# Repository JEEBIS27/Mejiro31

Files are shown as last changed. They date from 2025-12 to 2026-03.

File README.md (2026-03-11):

# Mejiro31

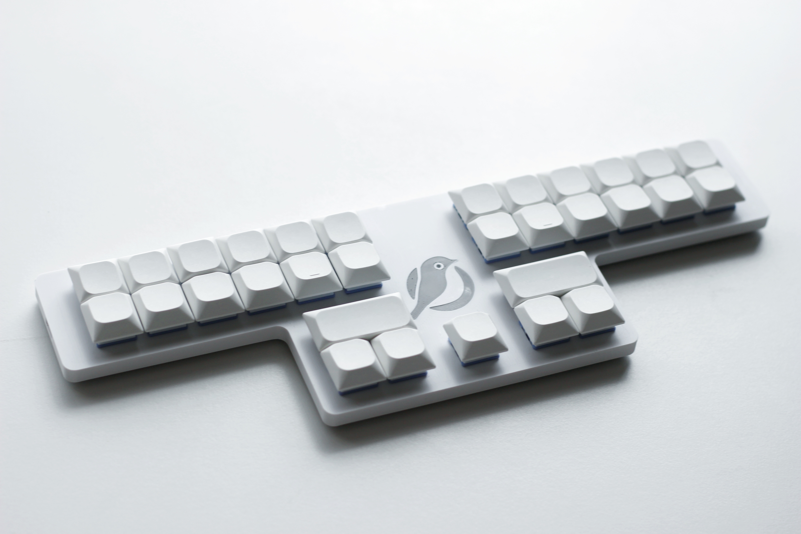
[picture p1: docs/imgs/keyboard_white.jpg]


## 組み立て方 / How to Build
- [Mejiro31 の組み立て方](/docs/BUILD.md)
- [How to Build Mejiro31](/docs/BUILD_EN.md)

## 使い方 / How to Use
- [Mejiro31 の使い方](/docs/USAGE.md)
- [How to Use Mejiro31](/docs/USAGE_EN.md)

## ファームウェア一覧 / Firmware List

### 日本語配列用 / Firmware for Japanese Layout
- [QWERTY 配列](https://github.com/JEEBIS27/Mejiro31/releases/download/v0.3.6/mejiro31_jp_qwerty.uf2)
- [Dvorak 配列](https://github.com/JEEBIS27/Mejiro31/releases/download/v0.3.6/mejiro31_jp_dvorak.uf2)
- [Boo 配列](https://github.com/JEEBIS27/Mejiro31/releases/download/v0.3.6/mejiro31_jp_boo.uf2)
- [Colemak 配列](https://github.com/JEEBIS27/Mejiro31/releases/download/v0.3.6/mejiro31_jp_colemak.uf2)
- [Colemak-DH 配列](https://github.com/JEEBIS27/Mejiro31/releases/download/v0.3.6/mejiro31_jp_colemak-dh.uf2)
- [Workman 配列](https://github.com/JEEBIS27/Mejiro31/releases/download/v0.3.6/mejiro31_jp_workman.uf2)
- [Graphite 配列](https://github.com/JEEBIS27/Mejiro31/releases/download/v0.3.6/mejiro31_jp_graphite.uf2)
- [Astarte 配列](https://github.com/JEEBIS27/Mejiro31/releases/download/v0.3.6/mejiro31_jp_astarte.uf2)
- [Eucalyn 配列](https://github.com/JEEBIS27/Mejiro31/releases/download/v0.3.6/mejiro31_jp_eucalyn.uf2)
- [Eucalyn 改](https://github.com/JEEBIS27/Mejiro31/releases/download/v0.3.6/mejiro31_jp_eucalyn-biacco.uf2)
- [Tomisuke 配列](https://github.com/JEEBIS27/Mejiro31/releases/download/v0.3.6/mejiro31_jp_tomisuke.uf2)
- [大西配列](https://github.com/JEEBIS27/Mejiro31/releases/download/v0.3.6/mejiro31_jp_o24.uf2)
- [Merlin 配列](https://github.com/JEEBIS27/Mejiro31/releases/download/v0.3.6/mejiro31_jp_merlin.uf2)
### 英語配列用 / Firmware for English Layout
- [QWERTY Layout](https://github.com/JEEBIS27/Mejiro31/releases/download/v0.3.6/jeeb1s_mejiro31_en_qwerty.uf2)
- [Dvorak Layout](https://github.com/JEEBIS27/Mejiro31/releases/download/v0.3.6/mejiro31_en_dvorak.uf2)
- [Boo Layout](https://github.com/JEEBIS27/Mejiro31/releases/download/v0.3.6/mejiro31_en_boo.uf2)
- [Colemak Layout](https://github.com/JEEBIS27/Mejiro31/releases/download/v0.3.6/mejiro31_en_colemak.uf2)
- [Colemak-DH Layout](https://github.com/JEEBIS27/Mejiro31/releases/download/v0.3.6/mejiro31_en_colemak-dh.uf2)
- [Workman Layout](https://github.com/JEEBIS27/Mejiro31/releases/download/v0.3.6/mejiro31_en_workman.uf2)
- [Graphite Layout](https://github.com/JEEBIS27/Mejiro31/releases/download/v0.3.6/mejiro31_en_graphite.uf2)
- [Gallium Layout](https://github.com/JEEBIS27/Mejiro31/releases/download/v0.3.6/mejiro31_en_gallium.uf2)
- [Handsdown-neu Layout](https://github.com/JEEBIS27/Mejiro31/releases/download/v0.3.6/mejiro31_en_handsdown-neu.uf2)
- [Sturdy Layout](https://github.com/JEEBIS27/Mejiro31/releases/download/v0.3.6/mejiro31_en_sturdy.uf2)
- [Canary Layout](https://github.com/JEEBIS27/Mejiro31/releases/download/v0.3.6/mejiro31_en_canary.uf2)
- [Engram Layout](https://github.com/JEEBIS27/Mejiro31/releases/download/v0.3.6/mejiro31_en_engram.uf2)

## ビルド環境の構築 / How to Build Firmware

ファームウェアのソースコード / Firmware Source Code
- https://github.com/JEEBIS27/qmk_firmware/tree/master/keyboards/jeebis/mejiro31

ファームウェアをクローンする / Cloning the Repo for Firmware Build
```
git clone https://github.com/JEEBIS27/qmk_firmware.git
```

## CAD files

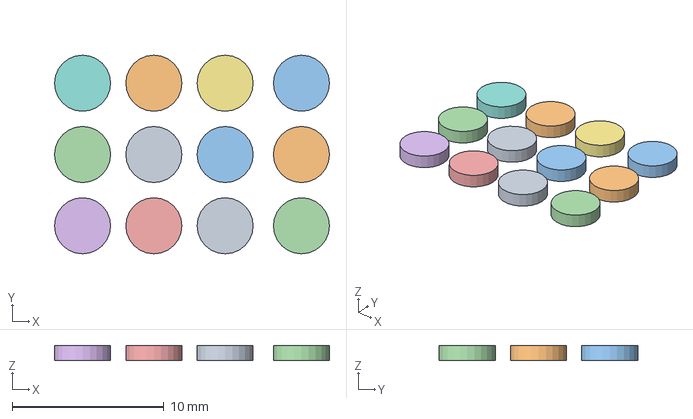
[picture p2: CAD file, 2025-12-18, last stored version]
3D/Mejiro31-PCBA_eye.3mf
18.1 x 13.1 x 1.00 mm
Mejiro31-PCBA_eye x 12

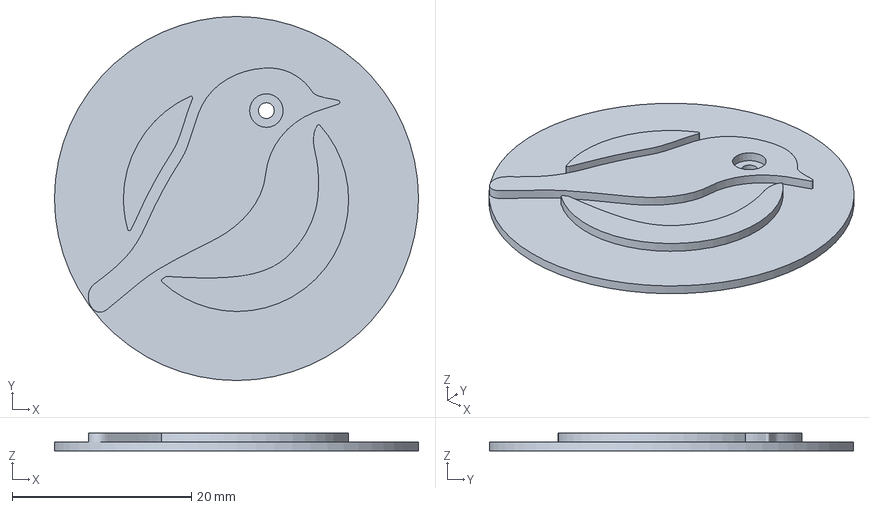
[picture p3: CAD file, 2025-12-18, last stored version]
3D/Mejiro31-PCBA_icon.3mf
40.6 x 40.6 x 2.00 mm

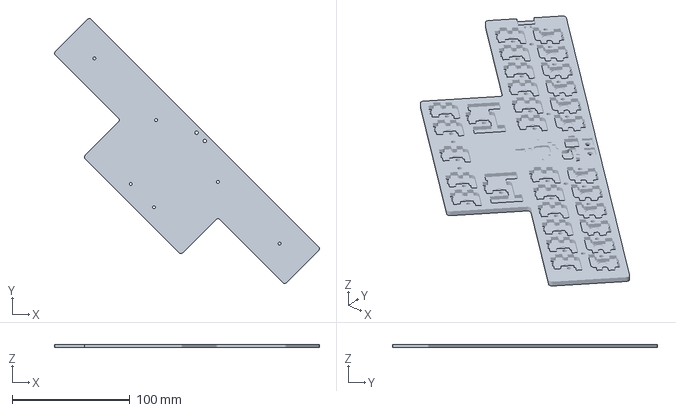
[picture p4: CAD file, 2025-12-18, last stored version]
3D/Mejiro31-PCBA_foam.3mf
224.7 x 224.7 x 2.60 mm

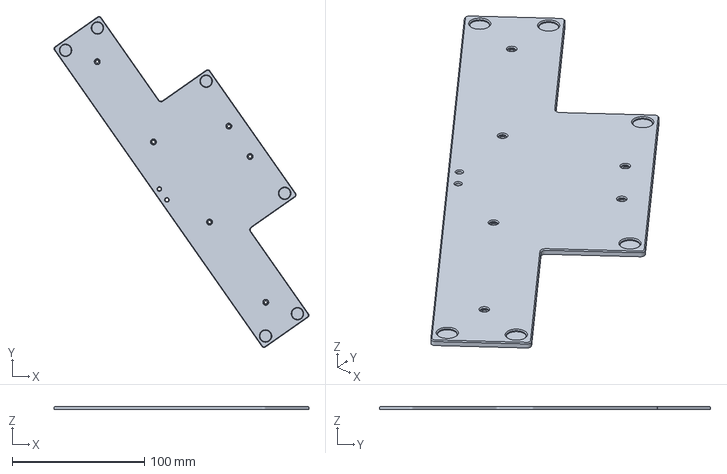
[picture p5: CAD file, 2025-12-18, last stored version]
3D/Mejiro31-PCBA_bottom.3mf
192.6 x 250.1 x 2.50 mm

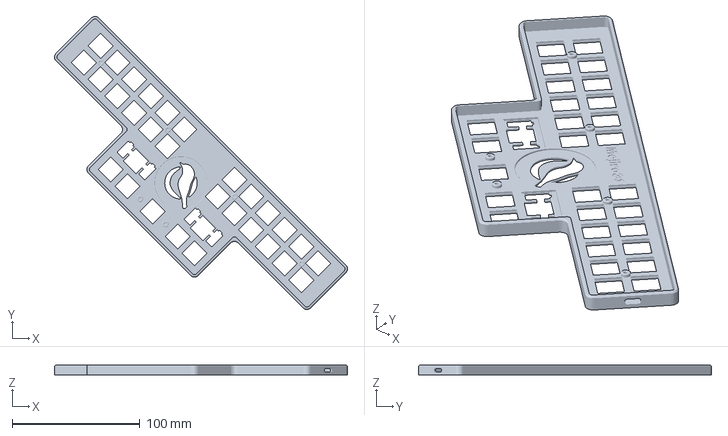
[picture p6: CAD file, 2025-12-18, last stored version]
3D/Mejiro31-PCBA_top.3mf
229.0 x 229.0 x 7.60 mm

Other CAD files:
3D/Mejiro31-PCBA_bottom.stl
3D/Mejiro31-PCBA_foam.stl
3D/Mejiro31-PCBA_icon.stl
3D/Mejiro31-PCBA_top.stl

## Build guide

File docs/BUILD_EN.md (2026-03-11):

# How to Build Mejiro31 ([Back to Start Page](../README.md))

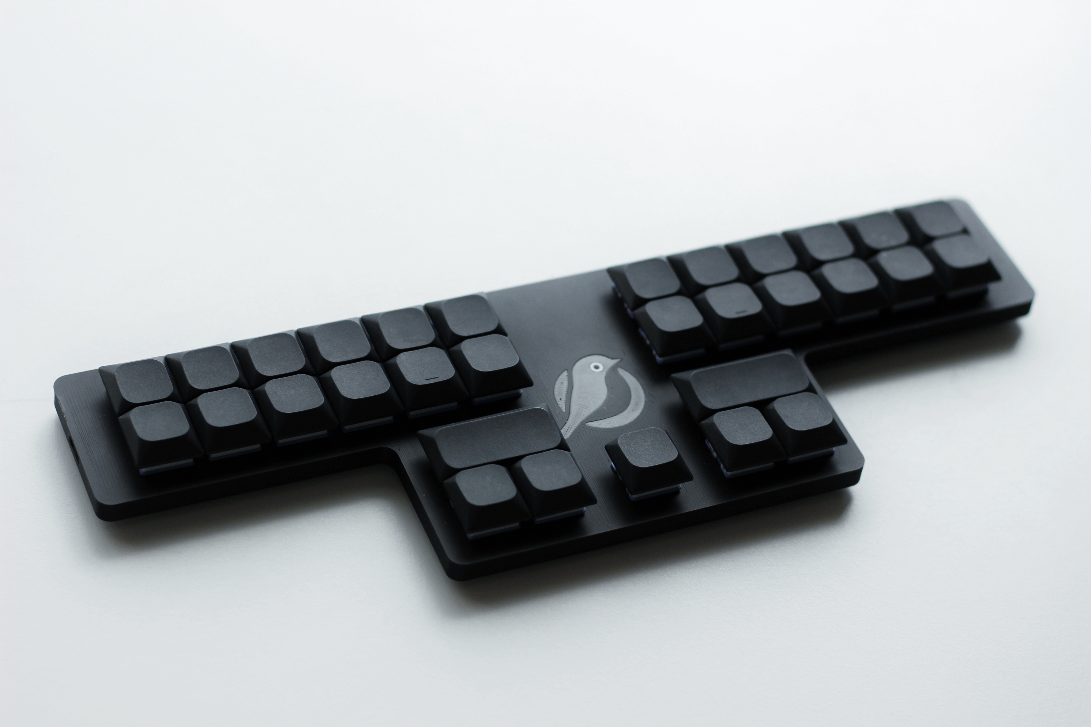
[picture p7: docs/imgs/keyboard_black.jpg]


## Table of Contents
  1. [What You Need Besides the Kit](#1-what-you-need-besides-the-kit)
  2. [Check the Contents](#2-check-the-contents)
  3. [Assembly](#3-assembly)
  4. [Troubleshooting](#4-troubleshooting)
  5. [Contact Us](#5-contact-us)

## 1. What You Need Besides the Kit

| Item | Quantity |
| ---- | --- |
| Keycaps | 31 |
| Key switches | 31 |
| USB-C cable | 1 |
| Precision screwdriver | 1 |
| Pliers | 1 |

### Key Switch Compatibility

Mejiro31 only supports low-profile key switches.

By default, only Cherry MX-compatible [Gateron low-profile 3.0](https://www.amazon.co.jp/dp/B0FJXBL4BF) switches work without soldering.

If you want to use the Kailh Choc V2 series, you need to solder [sockets for Kailh Choc](https://shop.yushakobo.jp/products/a01ps?variant=37665172553889).

### Recommended Key Switches

Here are some recommended switches for your reference.

| Switch | Feature | Actuation | Soldering |
| --- | --- | --- | --- |
| [Gateron low-profile 3.0](https://www.amazon.co.jp/dp/B0FJXBL4BF) | Standard feel | 50~43g | Not required |
| [Nuphy Gateron low-profile 3.0](https://sanyollc.com/products/nuphy-gateron-low-profile-3-0-switches) | POM material | 45~37g | Not required |
| [Lofree Hades POM](https://lofree.co.jp/products/hades-low-profile-pom-switches) | Silent | 40g | Required |
| [Kailh Saker mini](https://shop.talpkeyboard.com/products/kailh-saker-chocv2-linear) | Short travel | 37g | Required |
| [Kailh Choc v2 Panda V1](https://ja.aliexpress.com/item/1005008329710988.html) | Lightweight | 30g | Required |
| [Kailh Choc V1 Pink](https://shop.yushakobo.jp/products/pg1350?variant=44079245754599) | Lightest | 20g | Required |

## 2. Check the Contents

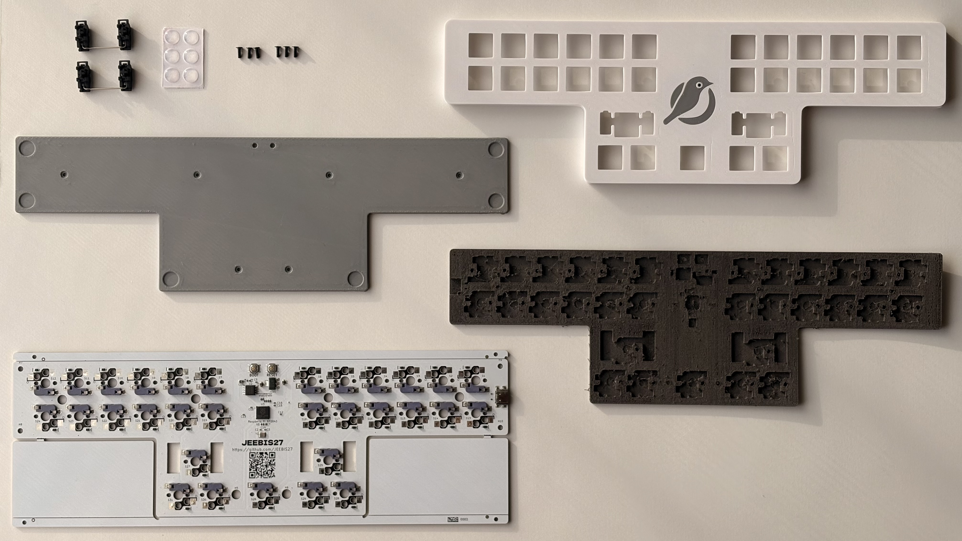
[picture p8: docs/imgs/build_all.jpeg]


| Included | Quantity |
| --- | --- |
| PCB | 1 |
| Top plate | 1 |
| Bottom plate | 1 |
| Foam plate | 1 |
| Stabilizers | 2 |
| Screws | 6 |
| Rubber feet | 6 |

## 3. Assembly

Download the firmware file first.

If you want to use a standard QWERTY layout, download [this file](https://github.com/JEEBIS27/Mejiro31/releases/download/v0.3.6/mejiro31_en_qwerty.uf2).

For other layouts, download from the links below:
- [QWERTY Layout](https://github.com/JEEBIS27/Mejiro31/releases/download/v0.3.6/mejiro31_en_qwerty.uf2)
- [Dvorak Layout](https://github.com/JEEBIS27/Mejiro31/releases/download/v0.3.6/mejiro31_en_dvorak.uf2)
- [Boo Layout](https://github.com/JEEBIS27/Mejiro31/releases/download/v0.3.6/mejiro31_en_boo.uf2)
- [Colemak Layout](https://github.com/JEEBIS27/Mejiro31/releases/download/v0.3.6/mejiro31_en_colemak.uf2)
- [Colemak-DH Layout](https://github.com/JEEBIS27/Mejiro31/releases/download/v0.3.6/mejiro31_en_colemak-dh.uf2)
- [Workman Layout](https://github.com/JEEBIS27/Mejiro31/releases/download/v0.3.6/mejiro31_en_workman.uf2)
- [Graphite Layout](https://github.com/JEEBIS27/Mejiro31/releases/download/v0.3.6/mejiro31_en_graphite.uf2)
- [Astarte Layout](https://github.com/JEEBIS27/Mejiro31/releases/download/v0.3.6/mejiro31_en_astarte.uf2)
- [Eucalyn Layout](https://github.com/JEEBIS27/Mejiro31/releases/download/v0.3.6/mejiro31_en_eucalyn.uf2)
- [Eucalyn Modified](https://github.com/JEEBIS27/Mejiro31/releases/download/v0.3.6/mejiro31_en_eucalyn.uf2)
- [Tomisuke Layout](https://github.com/JEEBIS27/Mejiro31/releases/download/v0.3.6/mejiro31_en_tomisuke.uf2)
- [Onishi Layout](https://github.com/JEEBIS27/Mejiro31/releases/download/v0.3.6/mejiro31_en_o24.uf2)
- [Merlin Layout](https://github.com/JEEBIS27/Mejiro31/releases/download/v0.3.6/mejiro31_en_merlin.uf2)
- [Gallium Layout](https://github.com/JEEBIS27/Mejiro31/releases/download/v0.3.6/mejiro31_en_gallium.uf2)
- [Handsdown-neu Layout](https://github.com/JEEBIS27/Mejiro31/releases/download/v0.3.6/mejiro31_en_handsdown-neu.uf2)
- [Sturdy Layout](https://github.com/JEEBIS27/Mejiro31/releases/download/v0.3.6/mejiro31_en_sturdy.uf2)
- [Canary Layout](https://github.com/JEEBIS27/Mejiro31/releases/download/v0.3.6/mejiro31_en_canary.uf2)
- [Engram Layout](https://github.com/JEEBIS27/Mejiro31/releases/download/v0.3.6/mejiro31_en_engram.uf2)

After downloading, hold the BOOT button on the PCB while connecting it to your PC.
(For updating the firmware later, hold the top-left key while connecting.)

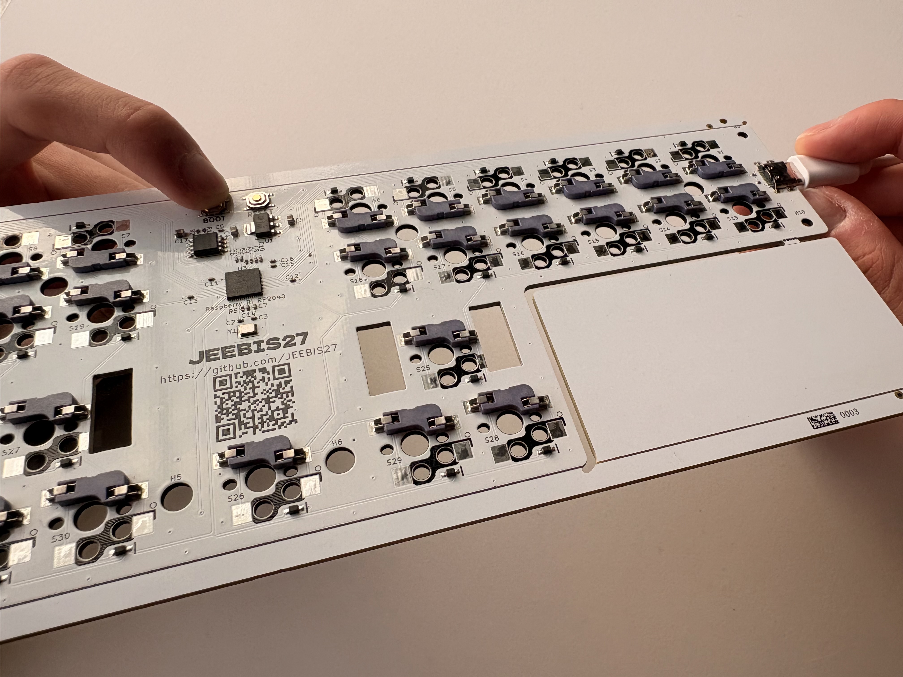
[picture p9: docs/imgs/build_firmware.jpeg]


When it appears as a drive, drag and drop the downloaded file onto it.

Once the drive automatically ejects, you are ready. (Depending on your PC settings, you might see a warning; you can ignore it.)

After flashing the firmware, start assembling.

Use pliers to remove the extra tabs from the PCB.

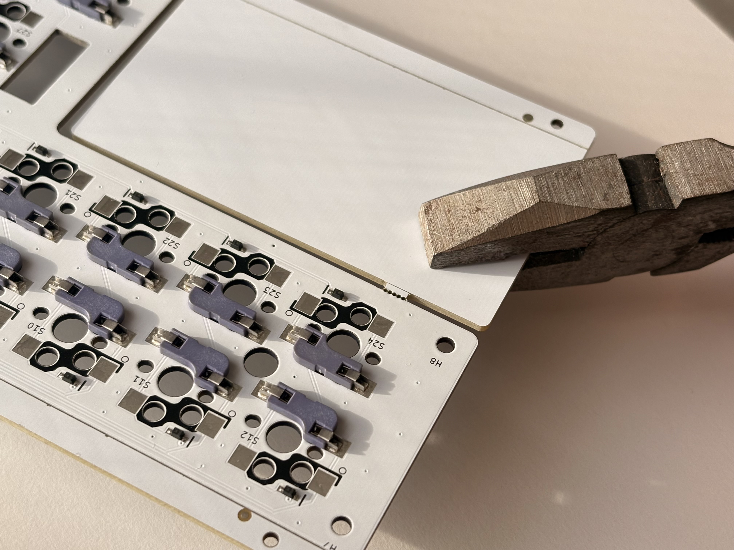
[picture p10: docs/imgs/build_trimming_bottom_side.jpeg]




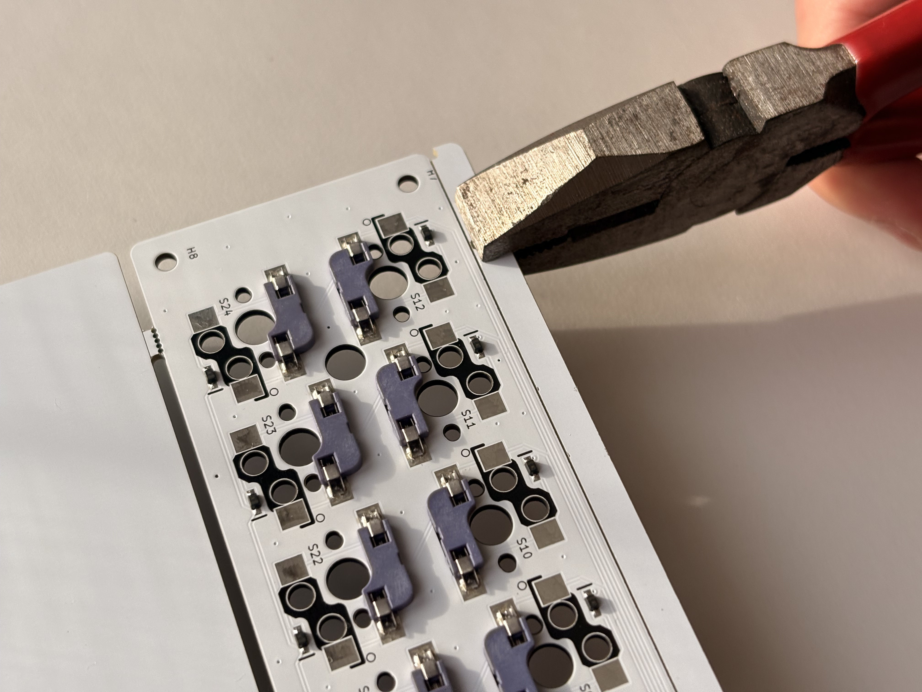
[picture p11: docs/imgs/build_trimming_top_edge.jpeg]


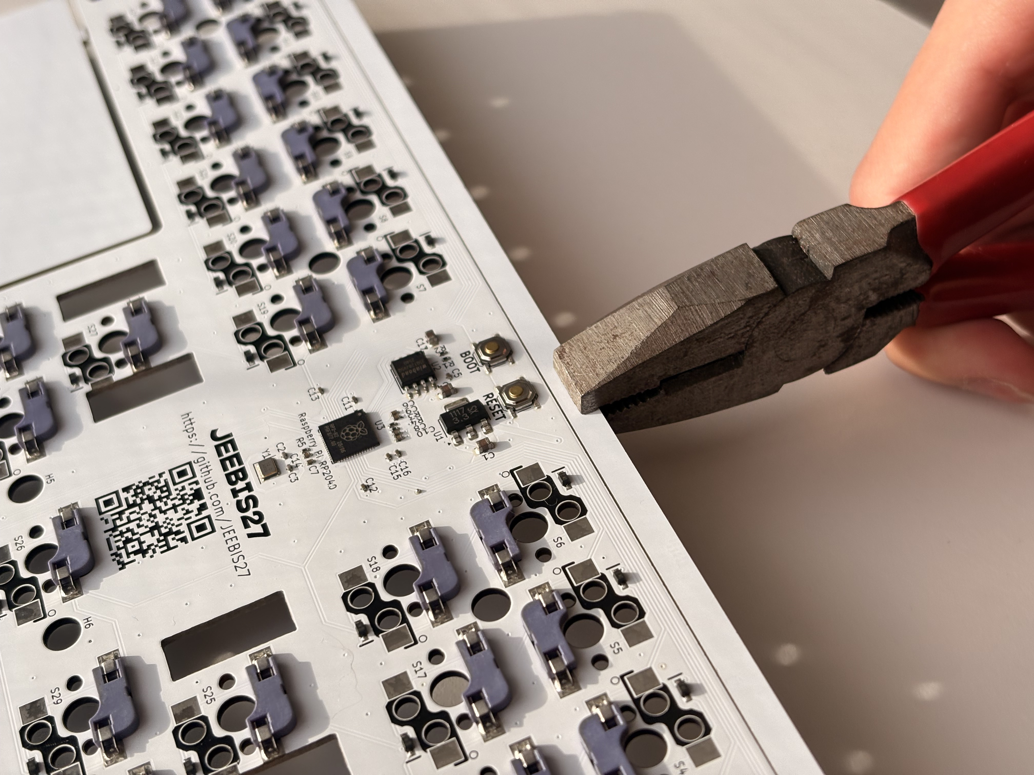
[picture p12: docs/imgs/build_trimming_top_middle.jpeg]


It should look like this after trimming.

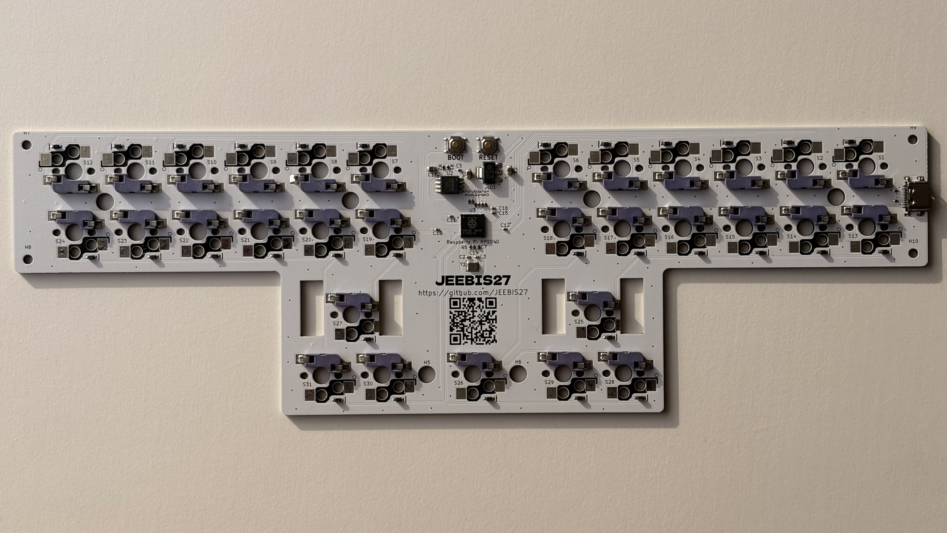
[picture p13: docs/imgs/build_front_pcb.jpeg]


Next, fit the PCB into the top plate.

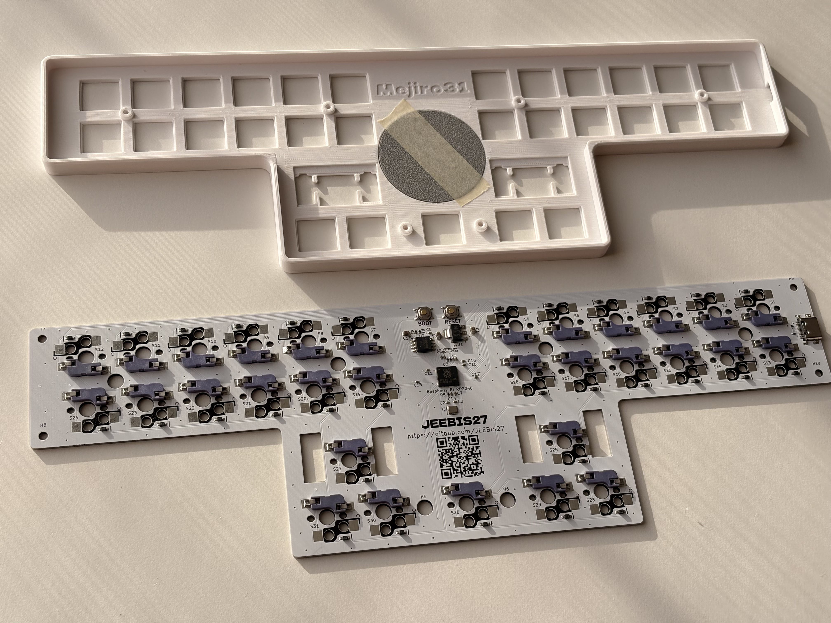
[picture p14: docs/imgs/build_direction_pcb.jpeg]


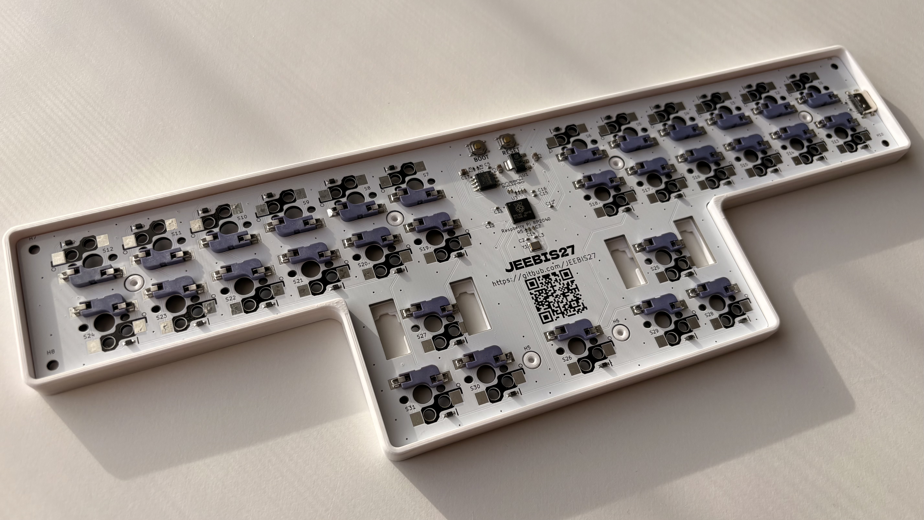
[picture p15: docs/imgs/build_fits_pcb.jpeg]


Make sure the pillars on the top plate align snugly with the holes on the PCB.

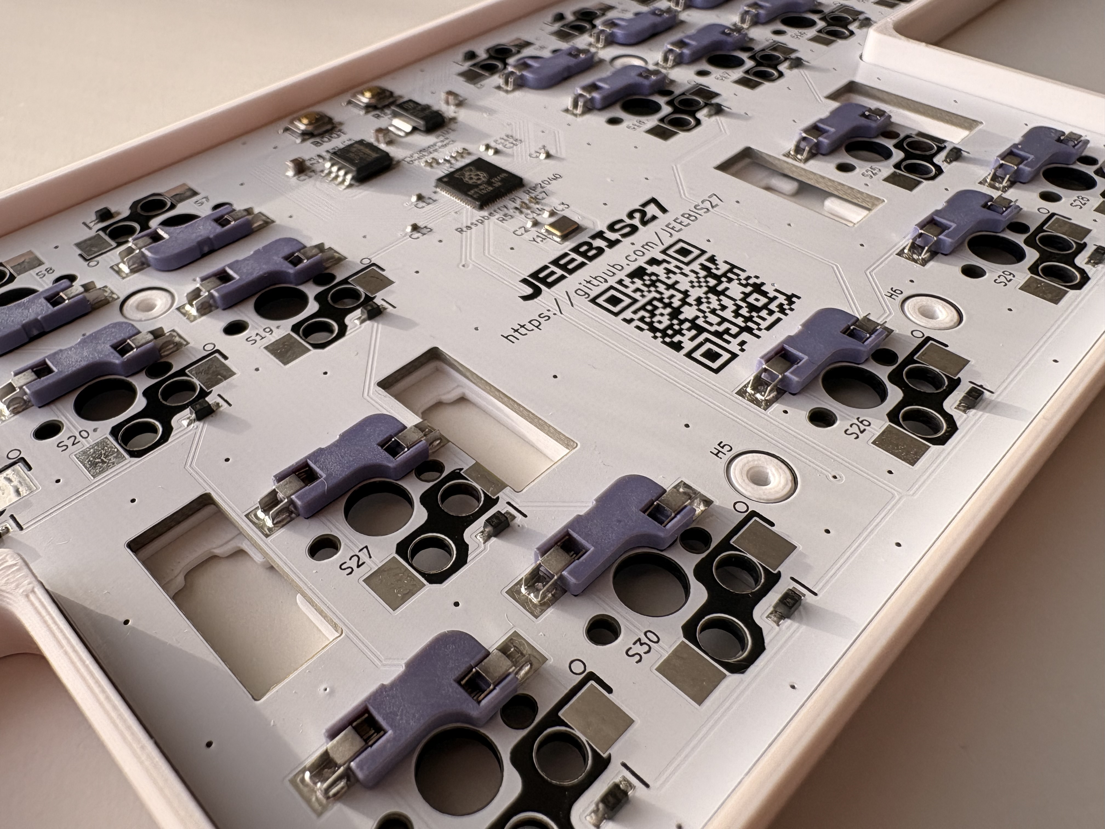
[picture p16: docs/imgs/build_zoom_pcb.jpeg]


Next, place the foam plate so the PCB components sit into its cutouts.

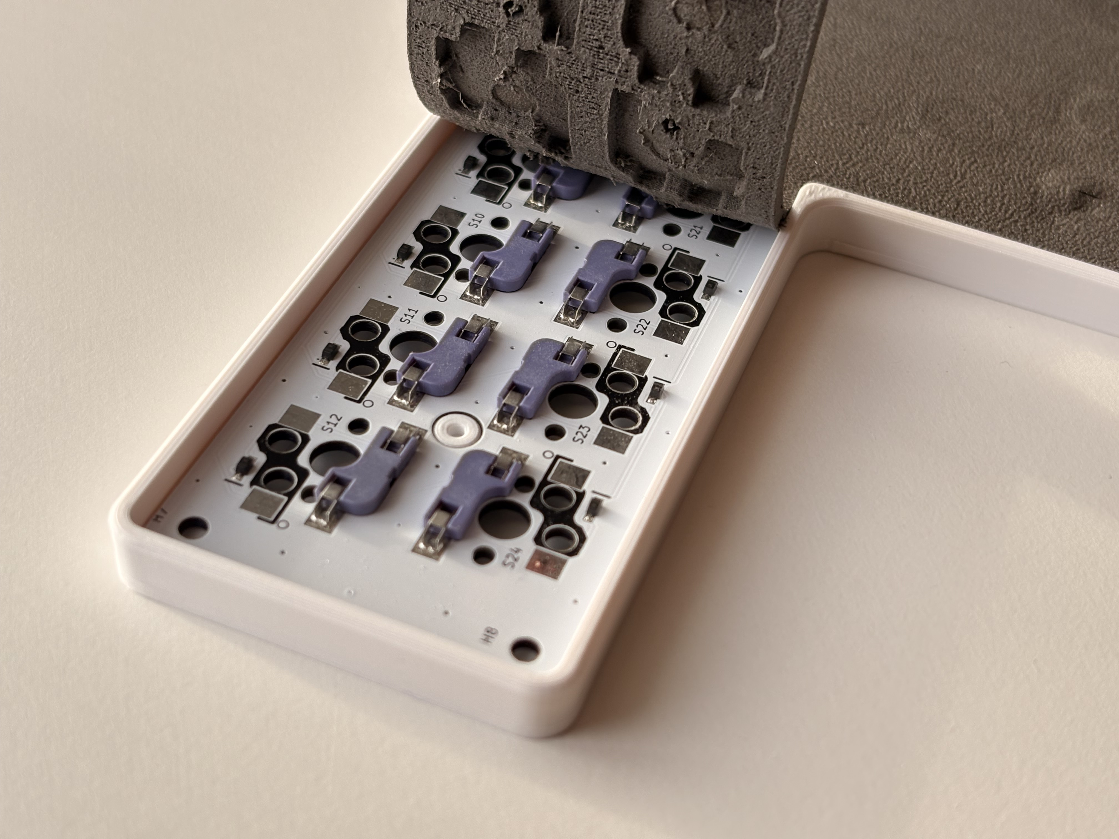
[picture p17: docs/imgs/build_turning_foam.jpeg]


Press the foam in firmly so it does not sit higher than the surrounding walls.

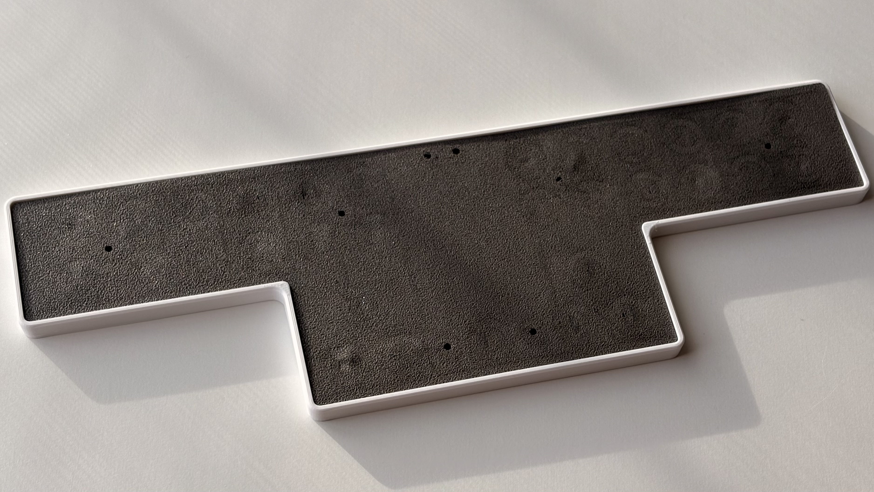
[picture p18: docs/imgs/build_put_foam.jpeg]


Place the bottom plate on top so that the countersunk screw holes are visible.

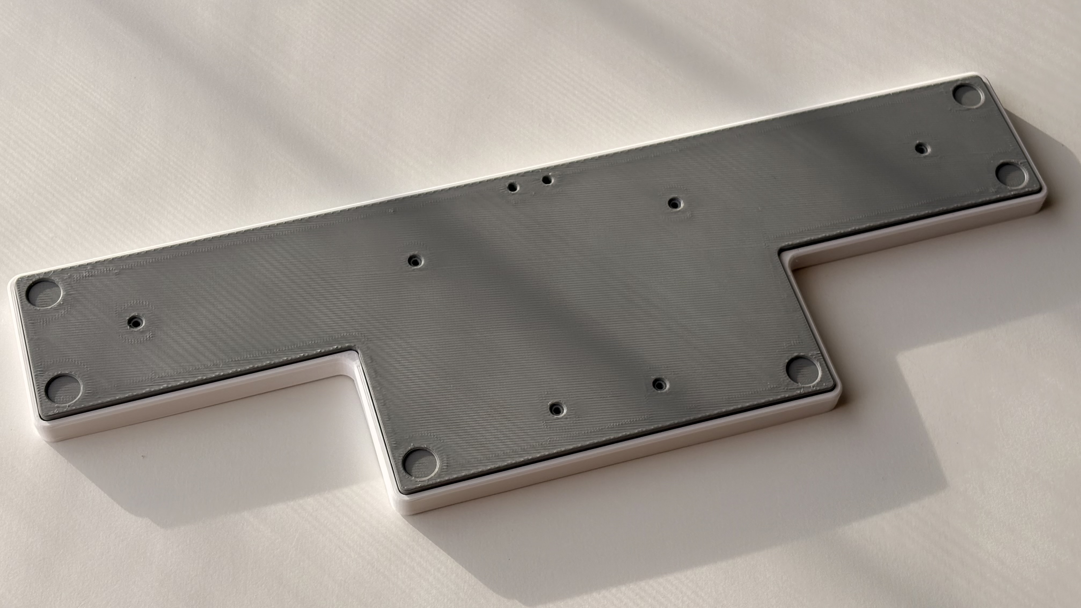
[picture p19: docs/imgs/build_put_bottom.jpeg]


Tighten the six screws.

(Press the foam down slightly while turning each screw. Stop once it becomes slightly resistant; overtightening can strip the holes and prevent the screws from holding.)

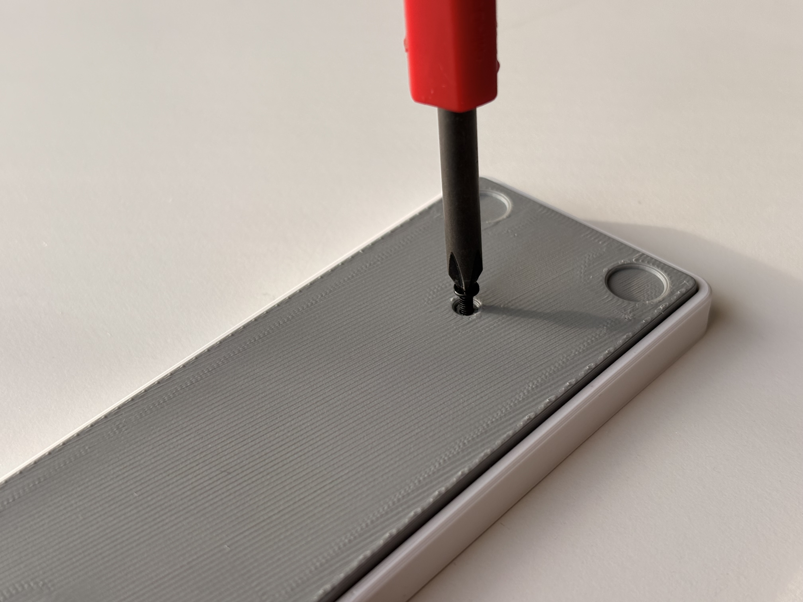
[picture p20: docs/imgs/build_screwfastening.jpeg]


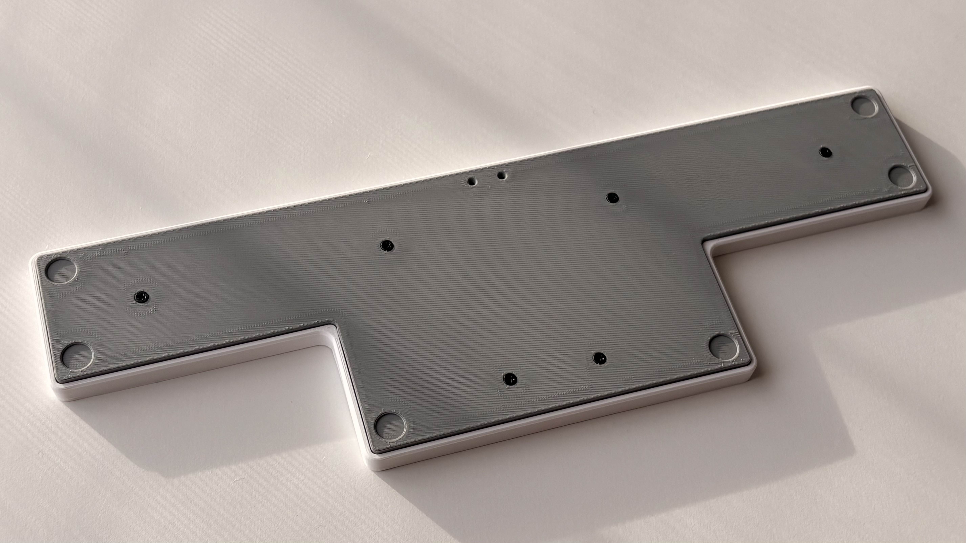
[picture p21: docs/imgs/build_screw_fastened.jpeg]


Stick the six rubber feet on.

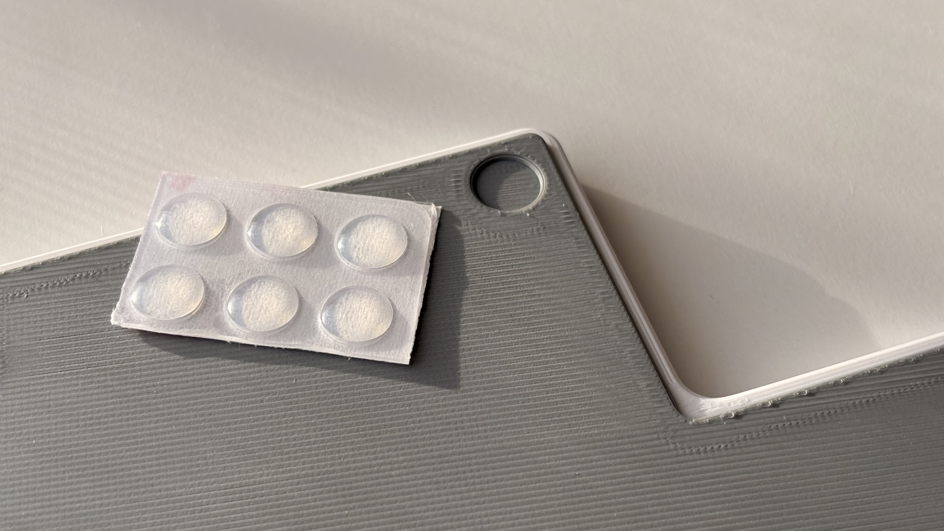
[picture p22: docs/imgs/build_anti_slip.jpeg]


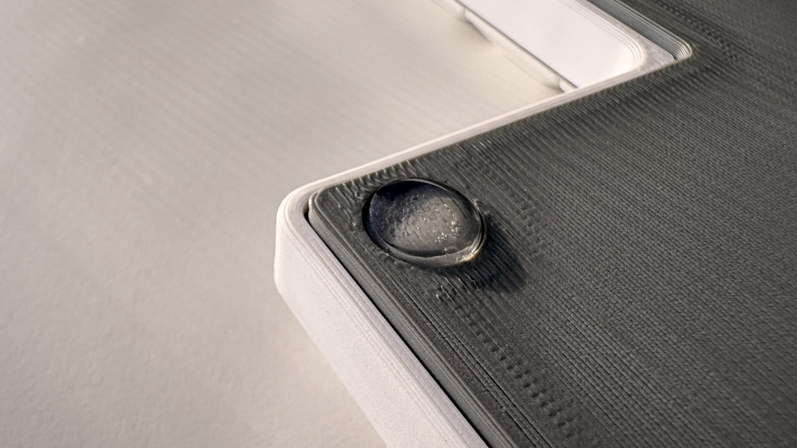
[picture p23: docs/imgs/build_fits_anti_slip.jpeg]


The base of the keyboard is now complete.

Install the two stabilizers in their positions.

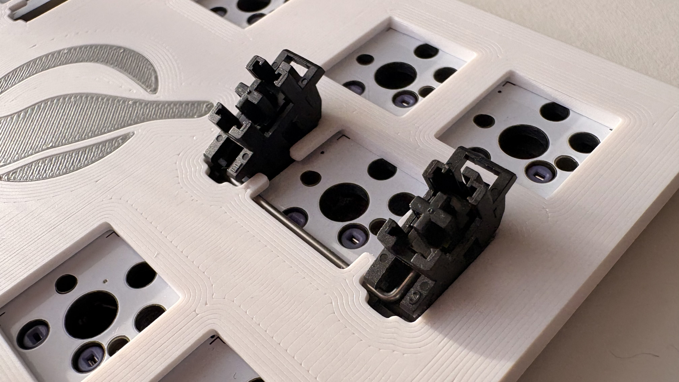
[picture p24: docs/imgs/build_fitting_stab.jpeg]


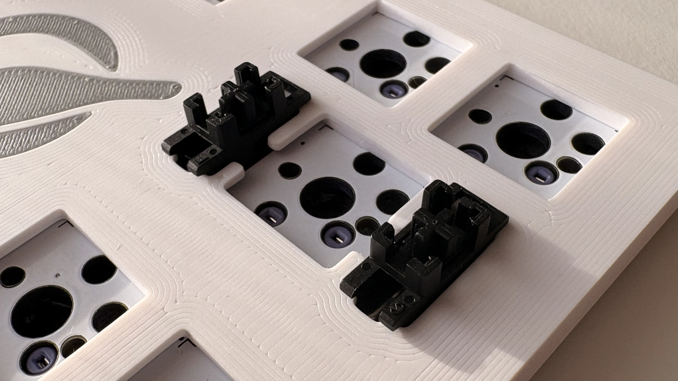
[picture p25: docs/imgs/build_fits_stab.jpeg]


Next, install the key switches. Align the pins with the holes before pressing them in.

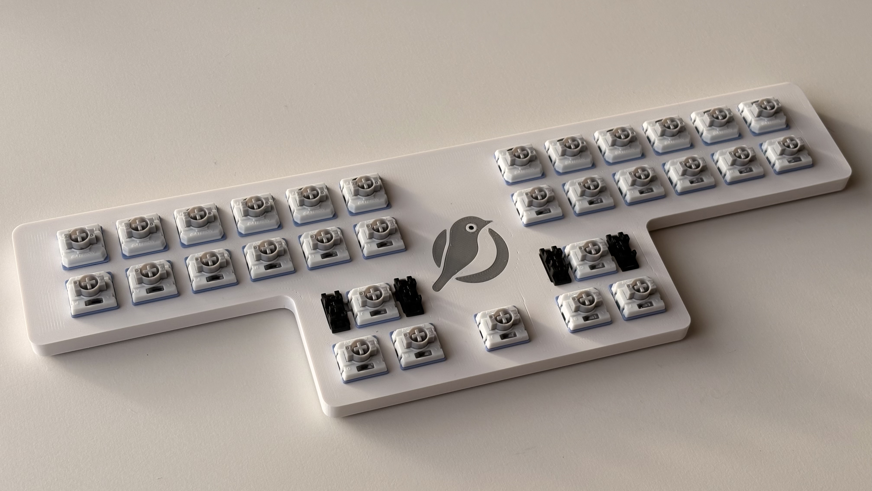
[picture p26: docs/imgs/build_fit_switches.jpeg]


Attach the keycaps.

All done!



## 4. Troubleshooting

- A key does not respond.

Check if the switch pins are bent. If they are, straighten them with tweezers or needle-nose pliers. Scratches on the PCB can also cause issues, so handle it carefully.

- Screw holes feel loose.

You can narrow the holes with masking tape. In some cases, you may need to replace the top plate.

- A part broke or went missing.

Some parts and PCBs may be available individually. Please see [Contact Us](#5-contact-us).

- Other issues

There might be a soldering error. Please reach out via [Contact Us](#5-contact-us).

## 5. Contact Us

Email `jeebis.iox@gmail.com`, or for fundamental issues, open an [Issue on the Mejiro31 GitHub repo](https://github.com/JEEBIS27/Mejiro31/issues).

[Back to Start Page](../README.md)

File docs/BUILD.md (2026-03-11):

# Mejiro31 の組み立て方 ([スタートページに戻る](../README.md))



## 目次
  1. [キット以外に必要なもの](#1-キット以外に必要なもの)
  2. [内容品の確認](#2-内容品の確認)
  3. [組み立て](#3-組み立て)
  4. [トラブルシュート](#4-トラブルシュート)
  5. [お問い合わせ](#5-お問い合わせ)

## 1. キット以外に必要なもの

| 必要なもの | 個数 |
| --- | ---- |
| キーキャップ | 31 |
| キースイッチ | 31 |
| USB-C ケーブル | 1 |
| 精密ドライバー | 1 |
| ペンチ | 1 |

### キースイッチの互換性

Mejiro31 では、low-profile のキースイッチのみが使用できます。

デフォルトでは Cherry MX 互換の [Gateron low-profile 3.0](https://www.amazon.co.jp/dp/B0FJXBL4BF) シリーズのみが、はんだ付け要らずで利用できるキースイッチです。

Kailh Choc V2 シリーズを利用したい方は、[Kailh Choc 専用のソケット](https://shop.yushakobo.jp/products/a01ps?variant=37665172553889)をはんだ付けで実装していただく必要があります。

### おすすめのキースイッチ

以下に、おすすめのキースイッチを紹介します。ぜひ参考にしてください。

| スイッチ名 | 特徴 | 押下圧 | はんだ付け |
| --- | ---- | ----- | --- |
| [Gateron low-profile 3.0](https://www.amazon.co.jp/dp/B0FJXBL4BF) | 標準的 | 50~43g | 不要 |
| [Nuphy Gateron low-profile 3.0](https://sanyollc.com/products/nuphy-gateron-low-profile-3-0-switches) | POM素材 | 45~37g | 不要 |
| [Lofree Hades POM](https://lofree.co.jp/products/hades-low-profile-pom-switches) | 静音 | 40g | 必要 |
| [Kailh Saker mini](https://shop.talpkeyboard.com/products/kailh-saker-chocv2-linear) | 短ストローク | 37g | 必要 |
| [Kailh Choc v2 Panda V1](https://ja.aliexpress.com/item/1005008329710988.html) | 軽量 | 30g | 必要 |
| [Kailh Choc V1 Pink](https://shop.yushakobo.jp/products/pg1350?variant=44079245754599) | 最軽量 | 20g | 必要 |

## 2. 内容品の確認



| 内容品 | 個数 |
| --- | --- |
| 基板 | 1 |
| トップレート | 1 |
| ボトムプレート | 1 |
| フォームプレート | 1 |
| スタビライザー | 2 |
| ネジ | 6 |
| ゴム足 | 6 |

## 3. 組み立て

まずはファームウェアのファイルをダウンロードします。

普通のQWERTY配列を使いたい場合は [こちら](https://github.com/JEEBIS27/Mejiro31/releases/download/v0.3.6/mejiro31_jp_qwerty.uf2) をダウンロードしてください。

その他の代替配列を使いたい場合は以下のリンクからダウンロードしてください。
- [QWERTY 配列](https://github.com/JEEBIS27/Mejiro31/releases/download/v0.3.6/mejiro31_jp_qwerty.uf2)
- [Dvorak 配列](https://github.com/JEEBIS27/Mejiro31/releases/download/v0.3.6/mejiro31_jp_dvorak.uf2)
- [Boo 配列](https://github.com/JEEBIS27/Mejiro31/releases/download/v0.3.6/mejiro31_jp_boo.uf2)
- [Colemak 配列](https://github.com/JEEBIS27/Mejiro31/releases/download/v0.3.6/mejiro31_jp_colemak.uf2)
- [Colemak-DH 配列](https://github.com/JEEBIS27/Mejiro31/releases/download/v0.3.6/mejiro31_jp_colemak-dh.uf2)
- [Workman 配列](https://github.com/JEEBIS27/Mejiro31/releases/download/v0.3.6/mejiro31_jp_workman.uf2)
- [Graphite 配列](https://github.com/JEEBIS27/Mejiro31/releases/download/v0.3.6/mejiro31_jp_graphite.uf2)
- [Astarte 配列](https://github.com/JEEBIS27/Mejiro31/releases/download/v0.3.6/mejiro31_jp_astarte.uf2)
- [Eucalyn 配列](https://github.com/JEEBIS27/Mejiro31/releases/download/v0.3.6/mejiro31_jp_eucalyn.uf2)
- [Eucalyn 改](https://github.com/JEEBIS27/Mejiro31/releases/download/v0.3.6/mejiro31_jp_eucalyn.uf2)
- [Tomisuke 配列](https://github.com/JEEBIS27/Mejiro31/releases/download/v0.3.6/mejiro31_jp_tomisuke.uf2)
- [大西配列](https://github.com/JEEBIS27/Mejiro31/releases/download/v0.3.6/mejiro31_jp_o24.uf2)
- [Merlin 配列](https://github.com/JEEBIS27/Mejiro31/releases/download/v0.3.6/mejiro31_jp_merlin.uf2)

ダウンロードしたら、基板のBOOTボタンを押しながら、PCと接続します。
(二回目以降に書き込む場合は、キーボードの一番左上のキーを押しながら接続してください。)



ドライブとして認識されるのでダウンロードしたファイルをドラッグ&ドロップします。

ドライブが自動的に消えれば準備完了です。(PCの設定によっては警告が出る場合もありますが大丈夫です。)

ファームウェアの書き込みが完了したら、組み立てを始めます。

まずは、基板についている余分な部分をペンチ等で切り取ります。









取り切るとこのようになります。



次に、トッププレートに基板をはめ込みます。





トッププレートの柱が基盤の穴にピッタリハマるようにはめ込んでください。



次に、フォームプレートをくぼみに基板の部品がはまるようにしてはめ込んでください。



フォームが壁より高い位置に来ないくらいまでしっかりと押し込みます。



次に、ボトムプレートをネジ穴のくぼみが見える形で上に乗せます。



6か所にネジを締めます。

(フォームを押し込むようにしてネジを回し、少し回りづらくなったくらいで止めます。強く締めすぎるとネジ穴が削れ、ネジが閉まらなくなる恐れがあります。)





6か所にゴム足を張ります。





これで、キーボードのベース部分は完成しました。

今度は、2か所にスタビライザーをはめ込みます。





次に、キースイッチをはめます。

キースイッチの足とはめ込む穴に気を付けながら、スイッチをはめ込みます。



キーキャップを取り付けます。

完成！



## 4. トラブルシュート

- キーが反応しない。

スイッチの金属端子の足が曲がっていないかご確認ください。曲がっていた場合はピンセットやラジオペンチを使うと伸ばしやすいです。また、基板に傷がつくと動作しなくなる場合があります。傷をつけないようにお気をつけください。

- ネジ穴が緩くなった。

マスキングテープ等でネジ穴を狭めることで対応してください。場合によってはトッププレートを再購入していただくことになります。

- 部品が壊れた/無くなった。

場合によっては基板や部品は単品で販売が可能ですので[お問い合わせ](#5-お問い合わせ)をお願いいたします。

- そのほかの不具合

はんだ付けにミスがある可能性があります。お手数ですが[お問い合わせ](#5-お問い合わせ)をお願いいたします。

## 5. お問い合わせ

お問い合わせは`jeebis.iox@gmail.com`へお願いします。

[スタートページに戻る](../README.md)

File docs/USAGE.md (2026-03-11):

# Mejiro31 の使い方 ([スタートページに戻る](../README.md))

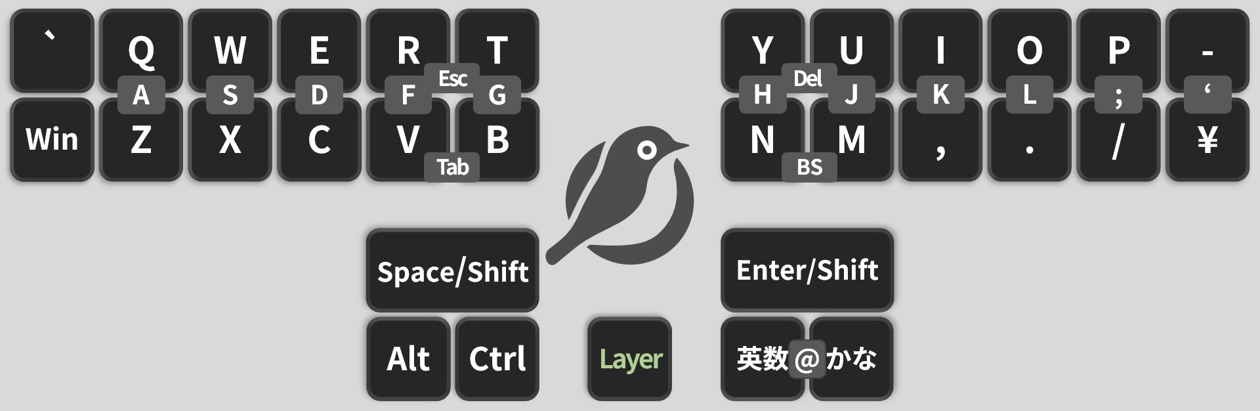
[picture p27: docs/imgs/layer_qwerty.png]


## 目次
  1. [キーレイアウト](#キーレイアウト)
     - [KEYBOARD レイヤー](#keyboard-レイヤー)
     - [STENO レイヤー](#steno-レイヤー)
     - [NUMBER レイヤー](#number-レイヤー)
     - [FUNCTION レイヤー](#function-レイヤー)
  2. [キーの入れ替え方法](#キーの入れ替え方法)
  3. [高度なカスタム](#高度なカスタム)
  4. [お問い合わせ](#お問い合わせ)

## キーレイアウト

デフォルトではこのようなキー配置になっています。

### KEYBOARD レイヤー

KEYBOARD レイヤーは標準のレイヤーです。

Mejiro31 を接続したときは毎回このレイヤーでスタートします。

[二段圧縮](https://note.com/jeebis_keyboard/n/ncbc327906050)を使用しており、キーの $1/3$ は同指の隣接キーの同時押しで入力します。

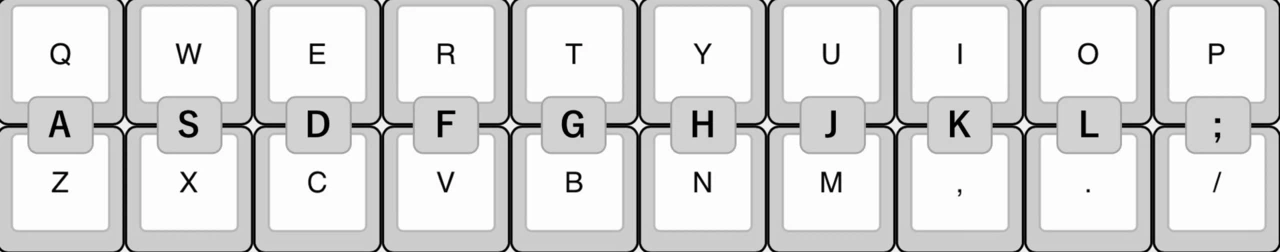
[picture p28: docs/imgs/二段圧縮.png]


もし QWERTY ではなく、Dvorakや大西配列のような代替レイアウトを使用したい場合は[スタートページ](../README.md)のファームウェア一覧の章をご覧いただき、使いたいレイアウトのファームウェアをダウンロードして書き込むことができます。もし他のレイアウトを追加してほしい場合は GitHub の [Issues](https://github.com/JEEBIS27/Mejiro31/issues) からリクエストしてください。

また、左右のスペースバーはそれぞれ Space と Enter ですが、長押しで Shift キーとして動作します。

Shift キーを押したときの配列は以下のようになります。

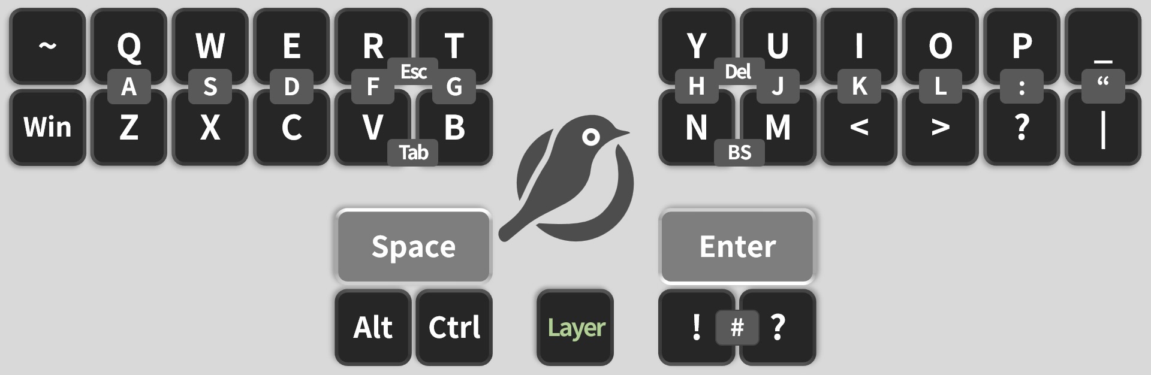
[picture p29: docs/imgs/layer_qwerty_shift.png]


真ん中のレイヤーキーを短く押すと STENO レイヤーに切り替わり、長押しで NUMBER レイヤーに切り替わります。

### STENO レイヤー
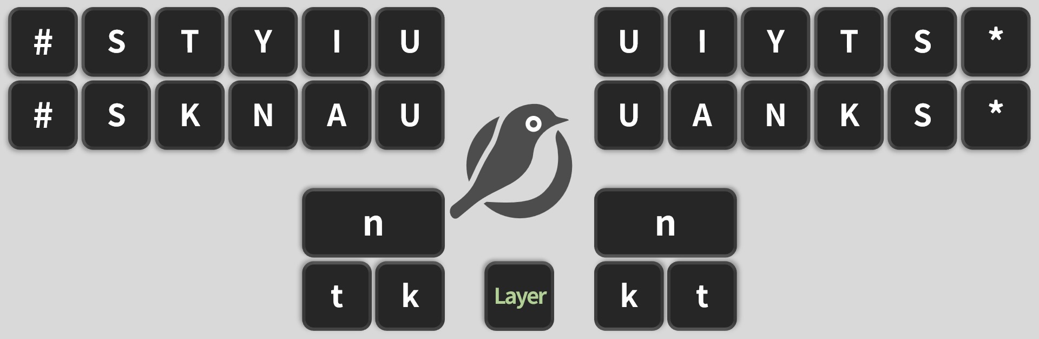
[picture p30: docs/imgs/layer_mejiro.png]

STENO レイヤーは、デフォルトでは QMK 版メジロ式が動作します。

※ QMK 版では以下の記号を直接出力できないため、IME に対応する専用の割り当てをする必要があります。

| 入力 |記号|
|---|----|
| z/ | ・ |
| z. | …  |
| * | ＊ |
| z* | ※  |
| z\|  | ‖  |
| zh | ←  |
| zj | ↓  |
| zk | ↑  |
| zl | →  |
| zhk  | ↖  |
| zhj  | ↙  |
| zlk  | ↗  |
| zlj  | ↘  |
| z[ | 『 |
| z] | 』 |
| z( | 【 |
| z) | 】 |
| < | 〈 |
| > | 〉 |
| z< | 《 |
| z> | 》 |

GoogleIME のローマテーブル設定ファイルは[こちら](https://github.com/JEEBIS27/Mejiro31/releases/download/v0.3.6/romantable.txt)からダウンロードして、インポートして使うことをおすすめします。

STENO レイヤーでは、後述の QMK 版メジロ式切り替えキーを長押しすることで、 GEMINI レイヤーに切り替えることができます。

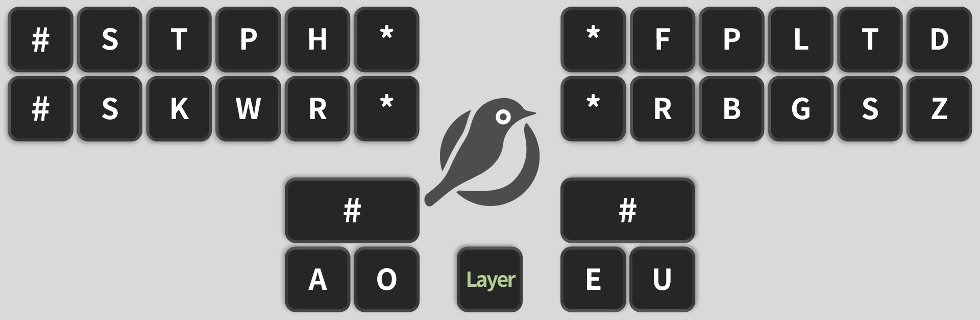
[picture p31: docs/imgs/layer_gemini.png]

GEMINI レイヤーは速記を使うために必要なレイヤーです。

速記を動かす Plover というソフト専用の出力が割り当たっています。

なので、基本的にこのキー配置を変更することはありません。

急にキーボードが入力できなくなったときは GEMINI レイヤーになってしまっていないかご確認ください。

真ん中のレイヤーキーを短く押すと KEYBOARD レイヤーに切り替わり、長押しで NUMBER レイヤーに切り替わります。

### NUMBER レイヤー
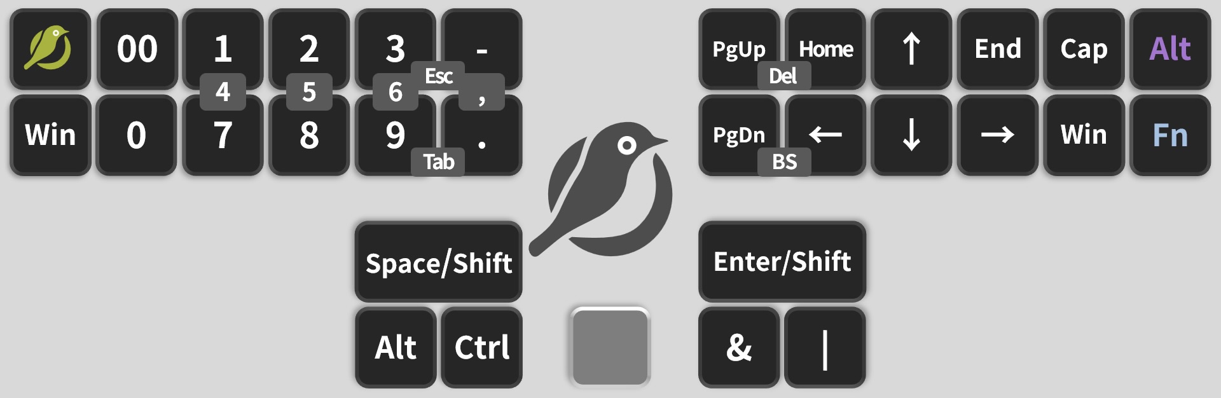
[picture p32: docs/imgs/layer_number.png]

NUMBER レイヤーには数字キーや矢印キー、その他機能キーが割り当たっています。

0 の上のキーは 00 キーで、二つの 0 を出力します。

Shift キーを押したときの配列は以下のようになります。

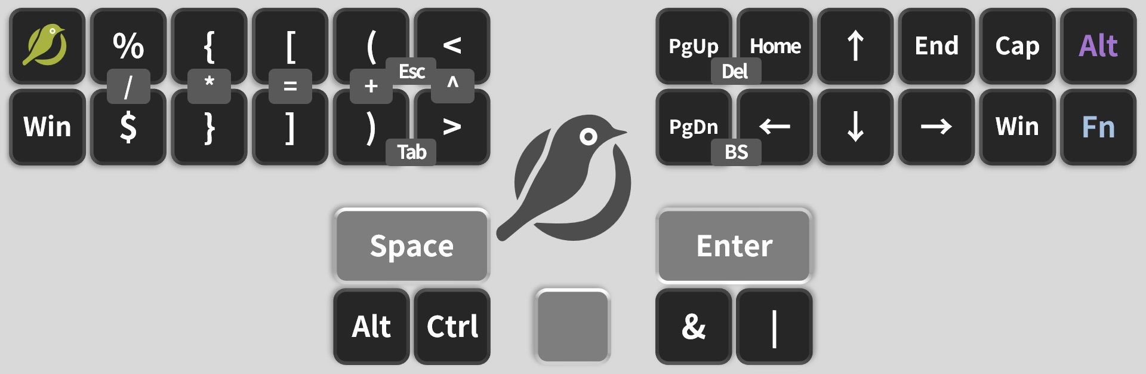
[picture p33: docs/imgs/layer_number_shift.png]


一番左の、上段のキーは QMK 版メジロ式切り替えキーで、これを長押しするとメジロ式は無効化され、 GEMINI レイヤーが有効化されます。もう一度長押しすると元に戻ります。

一番右の、上段のキーは長押しで代替レイアウトの有効・無効を切りかえるキーで、下段のキーは長押しで FUNCTION レイヤーに遷移するキーです。

### FUNCTION レイヤー
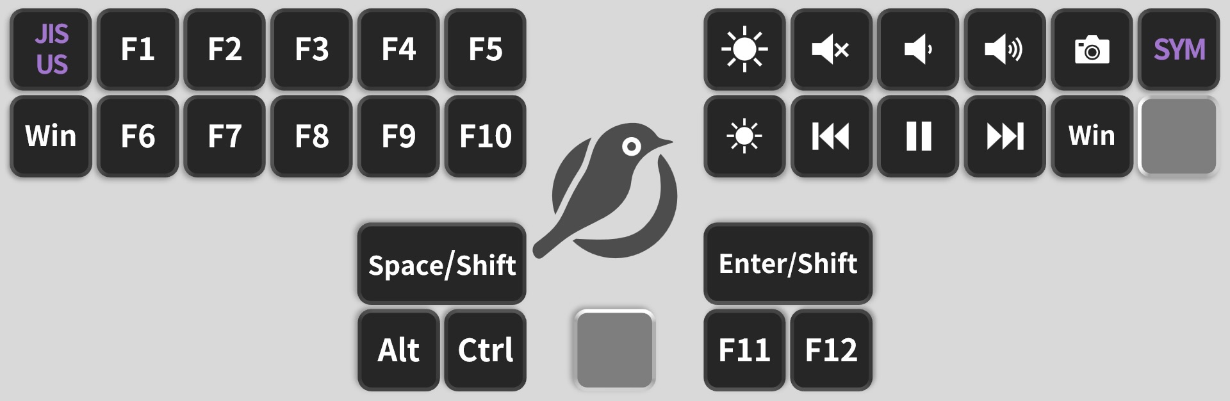
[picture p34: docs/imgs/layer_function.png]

FUNCTION レイヤーには F1 ~ F12 キーやメディアキーが割り当たっています。

一番左の、上段のキーは長押しで JIS モードと US モードを切り替えるキーです。

デフォルトでは JIS モードになっていますから、 PC の設定が US になっている場合はこのキーを長押しして US モードに切り替える必要があります。

一番右の、上段のキーは長押しで KEYBOARD レイヤーと NUMBER レイヤーの記号を普通のキーボード通りに変更するキーです。

これをオンにすることで普段通りに、例えば NUMBER レイヤーで `Shift + 2` を押すと `@` が出力されるようになります。

## キーの入れ替え方法

まずはこちらのファイルをダウンロードします。
- [via_keymap.json](https://github.com/JEEBIS27/Mejiro31/releases/download/v0.0.0/via_keymap.json)

次に、お好きなブラウザーから`VIA`にアクセスして、 DESIGN を選びます。

(以下のリンクからアクセスすると自動で DESIGN の画面に遷移します。)

- [VIA/DESIGN](https://www.usevia.app/design)

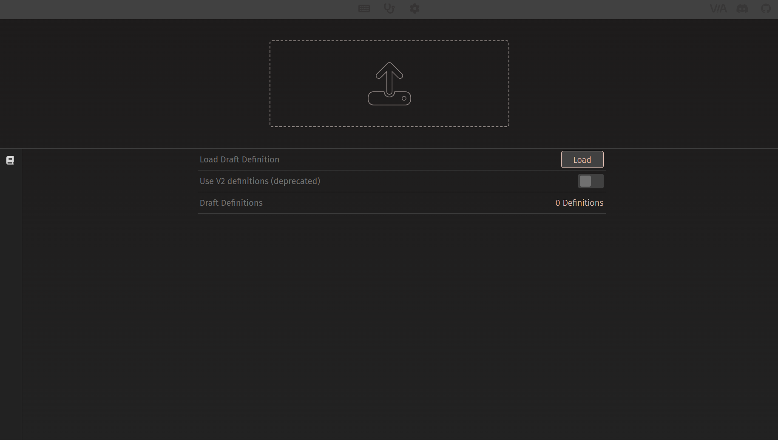
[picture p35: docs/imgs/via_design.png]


DESIGN タブを開いたら`Load`ボタンを押します。

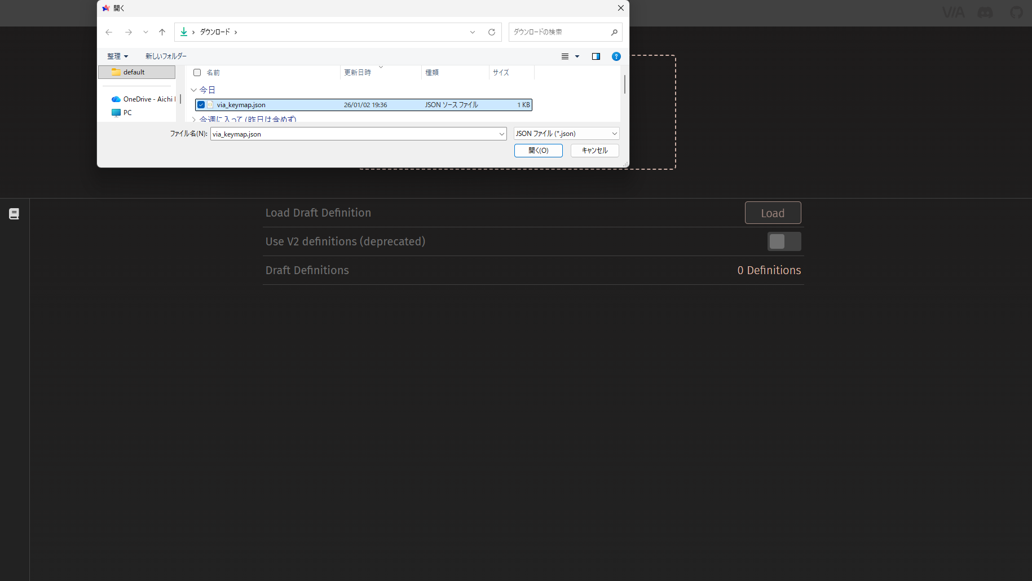
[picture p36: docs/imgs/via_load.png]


ここで先ほどダウンロードした JSON ファイルを選択し、正常に読み込まれると以下の画像のようにレイアウトが表示されます。

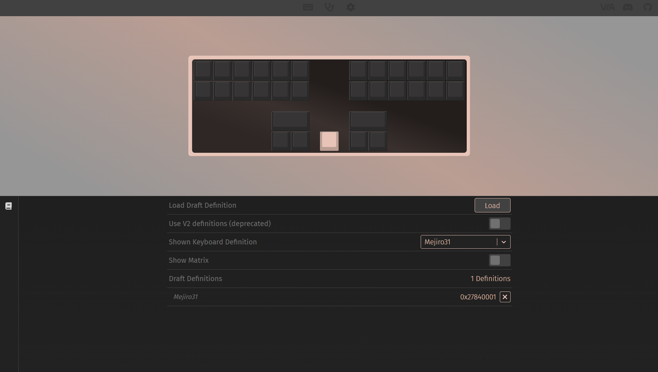
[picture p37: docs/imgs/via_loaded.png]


JSON ファイルの読み込みが完了後、 CONFIGURE タブに移動します。

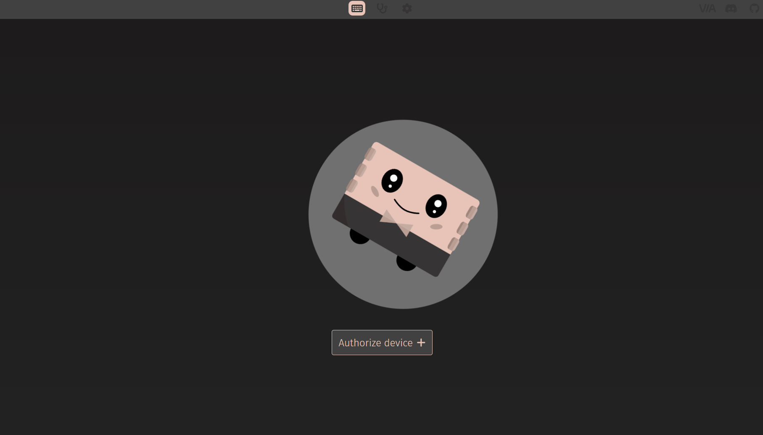
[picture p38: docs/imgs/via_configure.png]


CONFIGURE タブの`Authorize device`ボタンを押し、ポップアップ画面で Mejiro31 を選択して接続します。

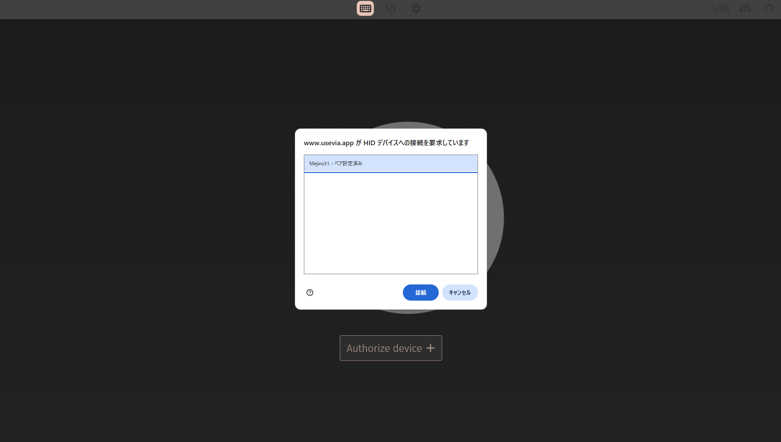
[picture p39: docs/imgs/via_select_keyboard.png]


するとキーマップ編集画面に遷移するので、キーボードのキーをクリックし変更したいキーを下から選んでクリックすることでキーを入れ替えることができます。

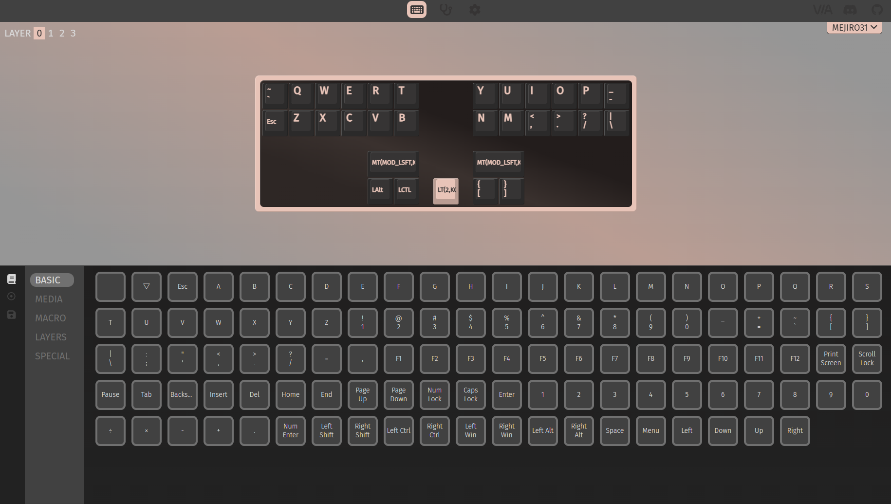
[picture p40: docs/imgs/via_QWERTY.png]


一度ここまでくれば、今後は VIA の CONFIGURE タブを開いて Mejiro31 を接続するだけでキーマップの変更が可能です。つまり、 JSON ファイルの読み込みは一度だけで大丈夫です。

(VIA からだと上下キーの同時押しの再定義ができません。なので事実上変えることができるのは NUMBER レイヤーや FUNCTION レイヤーのキーだけです。もし Dvorak や大西配列のような代替レイアウトを使用したい場合は[高度なカスタム](#高度なカスタム)の章をご覧ください。)

## 高度なカスタム

### 目次
  1. [高度なカスタムを行う方法](#高度なカスタムを行う方法)
     - [ファームウェアリポジトリをフォークする](#ファームウェアリポジトリをフォークする)
     - [ファームウェアのビルド環境構築方法](#ファームウェアのビルド環境構築方法)
  2. [高度なカスタムの紹介](#高度なカスタムの紹介)
     - [レイヤーごとの言語設定](#レイヤーごとの言語設定)
     - [代替レイアウトの有効化](#代替レイアウトの有効化)
     - [コンボの詳細設定](#コンボの詳細設定)
     - [config.h の設定](#config.h-の設定)

Mejiro31 は高度なカスタムとして、 QMK ファームウェアの設定を変更することでより細かい需要にこたえることができます。

### 高度なカスタムを行う方法

高度なカスタムを行うためには Mejiro31 のファームウェアリポジトリをあなたのアカウントでフォークし、ビルド環境を構築していただく必要があります。

そうやって書き換えたソースコードをビルドし、生成されたファームウェアを Mejiro31 に書き込むことで高度なカスタムが可能になります。

### ファームウェアリポジトリをフォークする

[github.com](https://github.com/) にアクセスします。

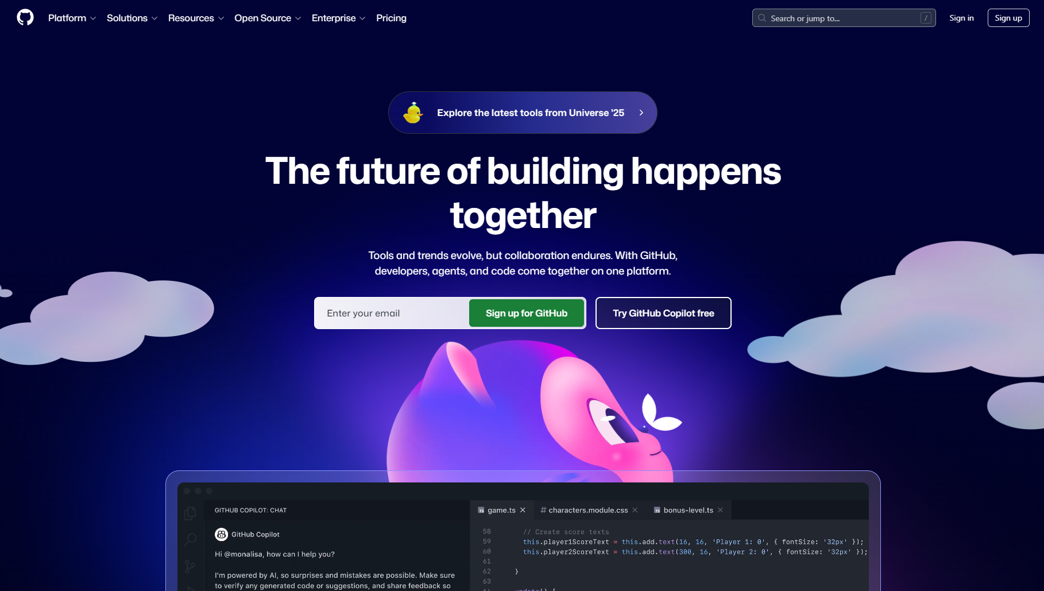
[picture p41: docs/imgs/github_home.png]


github アカウントを持っていない場合はここでサインアップして新しく作成してください。

アカウントを作成したら、以下のリンクから Mejiro31 の QMK ファームウェアリポジトリにアクセスします。
- [JEEBIS27/qmk_firmware](https://github.com/JEEBIS27/qmk_firmware)

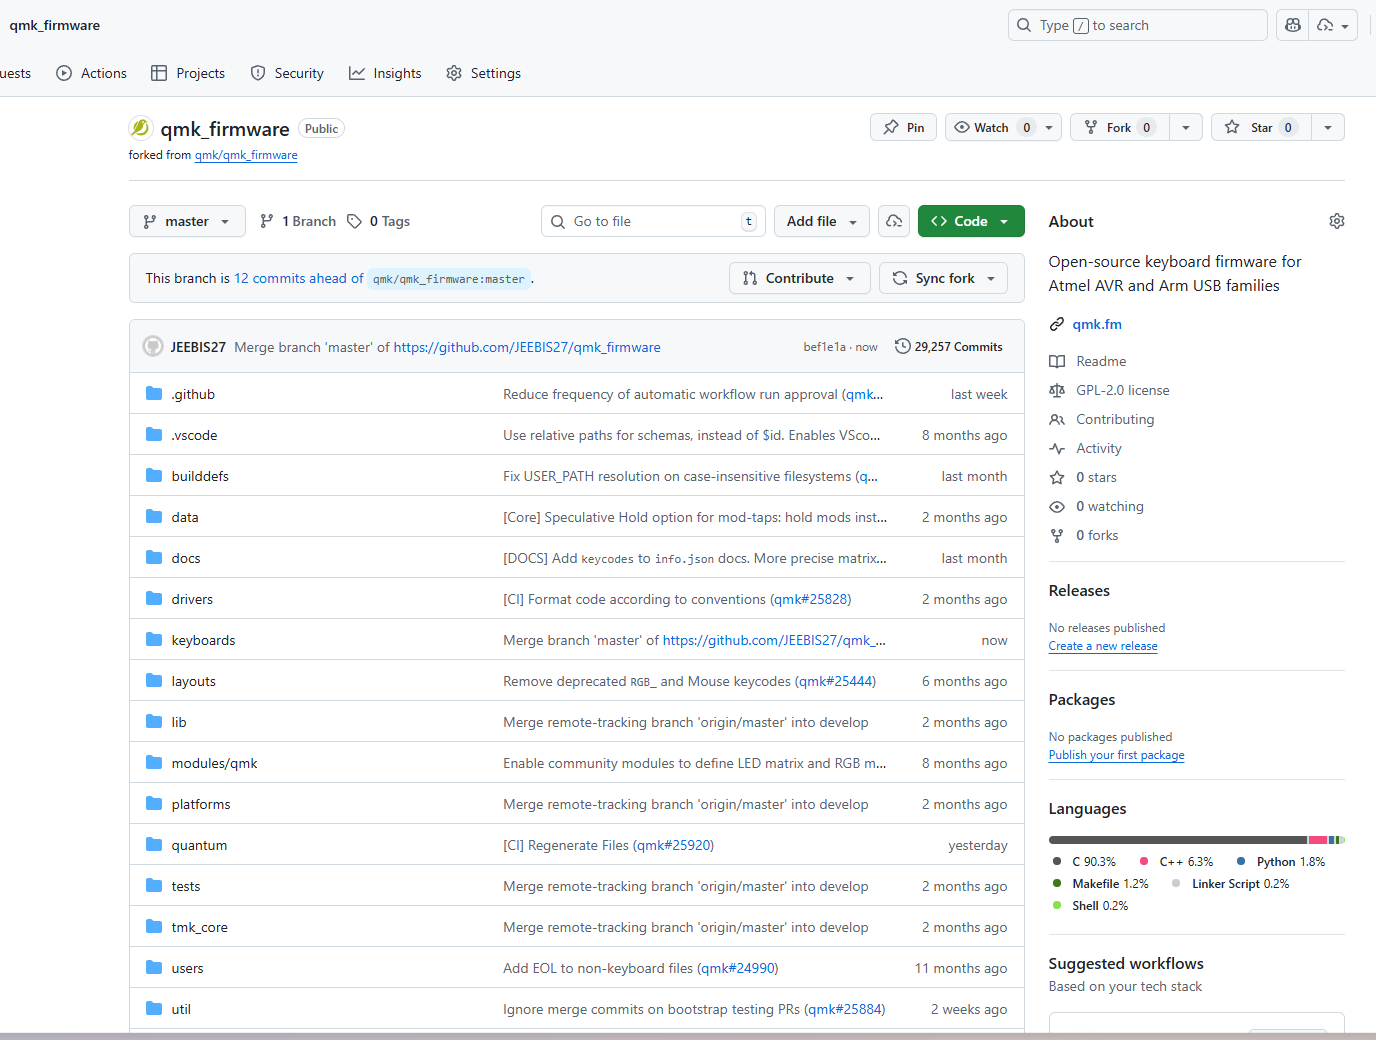
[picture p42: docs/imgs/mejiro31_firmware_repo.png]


右上の`Fork`ボタンを押して、あなたのアカウントにリポジトリをフォークします。

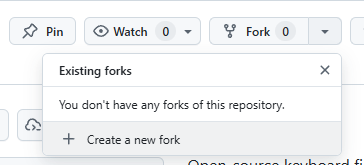
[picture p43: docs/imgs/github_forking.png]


`Fork`ボタンを押すと次のような画面になります。`Create fork`ボタンを押してフォークを完了させましょう。

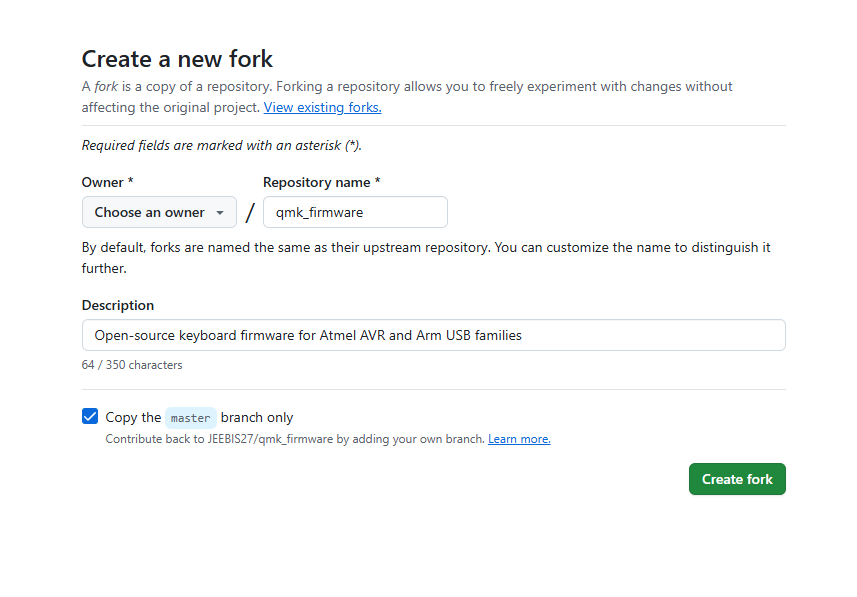
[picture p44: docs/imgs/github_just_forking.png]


フォークが完了すると、あなたのアカウントの下に Mejiro31 の QMK ファームウェアリポジトリが作成されます。

フォークしたあなたのリポジトリにアクセスし、緑色の`Code`ボタンを押して URL をコピーします。

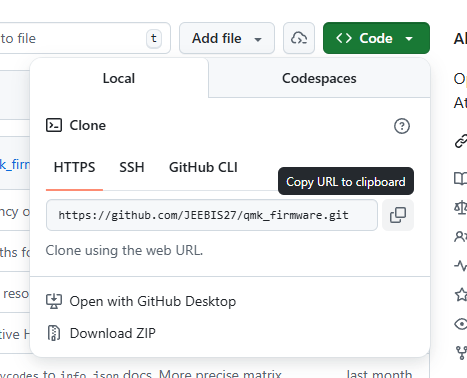
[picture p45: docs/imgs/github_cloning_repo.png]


次の[ファームウェアのビルド環境構築方法](#ファームウェアのビルド環境構築方法)の章でこの URL を使用します。

### ファームウェアのビルド環境構築方法

PC 環境によってやり方が異なるのでここでは詳しく紹介しませんが、以下の説明が参考になると思います。

- [QMKファームウェアビルド構築手順(Windows QMK MSYS編)](https://gist.github.com/e3w2q/4bc86e531d1c893d3d13af3e9895a94a)
- [MacでのQMKファームウェアビルド構築方法の参考記事](https://qiita.com/Nikk0r0/items/4089c194715185a124a5)

説明の中で`git clone <repository_url>`というようなコマンドが出てきたら、先ほどコピーしたあなたのフォークしたリポジトリの URL を使用するようにしてください。

### 高度なカスタムの紹介

ファームウェアのソースコードを編集することで、高度なカスタムが可能です。

#### レイヤーごとの言語設定

Mejiro31 ではレイヤーが切り替わるごとに、設定した言語に対応して IME を自動で切り替えることができます。

この機能によって、真ん中のレイヤーキーをキーボード・ステノモードの切り替えキーかつ IME 切り替えキーとして使用することができます。

デフォルトでは、ステノモードはメジロ式で日本語入力、キーボードモードでは英語入力を行うように設定されています。

高度なカスタムではこれを、例えば、日本語入力はローマ字、英語入力は速記で行うという場合、 QWERTY レイヤーで IME ON 、 STENO レイヤーでは IME OFF に自動で切り替えるようにすることができます。

Mejiro31 の言語設定をするにはまず、あなたがフォークしたリポジトリの`keyboards/jeebis/mejiro31/keymaps/jp_default/keymap.c`を開きます。

すると 76 行目あたりに以下のコードがあります。

```
<keymaps/jp_default/keymap.c>
// ============================================================
// 言語設定
// ============================================================
// 0:未使用, 1:英語, 2:日本語, 3:日英両方

static int stn_lang = 2;  // ステノモード時の言語
static int kbd_lang = 1;  // キーボードモード時の言語
```

ここでは、`stn_lang`が STENO レイヤー (ステノモード) の言語設定、`kbd_lang`が QWERTY レイヤー (キーボードモード) の言語設定を表しています。

それぞれの変数に以下の数値を設定することで言語設定を変更できます。

| 数値 | 言語設定 |
| ---- | --- |
| 1 | 英語 |
| 2 | 日本語  |
| 3 | 日英両方 |

キーボードで日本語入力、速記で英語入力を行いたい場合は以下のように設定します。

```
<keymaps/jp_default/keymap.c>
static int stn_lang = 2;  // ステノモード時の言語
static int kbd_lang = 1;  // キーボードモード時の言語
```

#### 代替レイアウト設定

ここでは日本語入力で大西配列を、英語入力で graphite を使う際の設定を例として紹介します。

まずは、`keyboards/jeebis/mejiro31/keymaps/jp_default/keymap.c`を開きます。

73 行目あたりに以下のコードがあります。
```
<keymaps/jp_default/keymap.c>
static alt_layout_def_t alt_en_layout = ALT_LAYOUT(qwerty);  // 英語モード時のレイアウト
static alt_layout_def_t alt_jp_layout = ALT_LAYOUT(qwerty);  // 日本語モード時のレイアウト
```

ここの`alt_en_layout`と`alt_jp_layout`変数はデフォルトでは qwerty に設定されています。

これを使いたい代替配列の名前に変更することで各言語時の代替レイアウトを設定できます。

```
<keymaps/jp_default/keymap.c>
static alt_layout_def_t alt_en_layout = ALT_LAYOUT(graphite);  // 英語モード時のレイアウト
static alt_layout_def_t alt_jp_layout = ALT_LAYOUT(o24);  // 日本語モード時のレイアウト
```
ここで言語を設定すると、NUMBER レイヤーの右親指下段にある英数・かなキーで IME を切り替えると自動でその言語の代替レイアウトに切り替わるようになります。

#### 代替レイアウトの定義追加

次に、自分で代替レイアウトのキーマップを定義する方法を紹介します。。

まずは、`keyboards/jeebis/mejiro31/alt_layouts_definitions.h`を開きます。
例えば、67 行目あたりに以下のコードがあります。

```
<keyboards/jeebis/mejiro31/alt_layouts_definitions.h>
// ====== GRAPHITE ======
static const alt_mapping_t graphite[] PROGMEM = {

    {KC_Q,    KC_B,    KC_B},
    {KC_W,    KC_L,    KC_L},
    {KC_E,    KC_D,    KC_D},
    {KC_R,    KC_W,    KC_W},
    {KC_T,    KC_Z,    KC_Z},
    {KC_Y,    KC_QUOT, KC_UNDS},
    {KC_U,    KC_F,    KC_F},
    {KC_I,    KC_O,    KC_O},
    {KC_O,    KC_U,    KC_U},
    {KC_P,    KC_J,    KC_J},
    {KC_MINS, KC_SCLN, KC_COLN},

    {KC_A,    KC_N,    KC_N},
    {KC_S,    KC_R,    KC_R},
    {KC_D,    KC_T,    KC_T},
    {KC_F,    KC_S,    KC_S},
    {KC_G,    KC_G,    KC_G},
    {KC_H,    KC_Y,    KC_Y},
    {KC_J,    KC_H,    KC_H},
    {KC_K,    KC_A,    KC_A},
    {KC_L,    KC_E,    KC_E},
    {KC_SCLN, KC_I,    KC_I},
    {KC_QUOT, KC_COMM, KC_QUES},

    {KC_Z,    KC_Q,    KC_Q},
    {KC_X,    KC_X,    KC_X},
    {KC_C,    KC_M,    KC_M},
    {KC_V,    KC_C,    KC_C},
    {KC_B,    KC_V,    KC_V},
    {KC_N,    KC_K,    KC_K},
    {KC_M,    KC_P,    KC_P},
    {KC_COMM, KC_DOT,  KC_RABK},
    {KC_DOT,  KC_MINS, KC_DQUO},
    {KC_SLSH, KC_SLSH, KC_LABK},
    {KC_BSLS, KC_BSLS, KC_PIPE},

};
```

ここで定義されている`alt_transform`関数が代替レイアウトのキーマップを定義しています。

ここでは graphite が定義されていますが、このマップをコピーして、あたらしく代替レイアウトを定義することができます。

定義方法は、左から、
1. キーボードレイアウトのキーコード(QWERTY)
2. 代替レイアウトでのキーコード
3. 代替レイアウトでのキーコード (Shift 押下時)
の順番でキーコードを定義していきます。

### コンボの詳細設定

Mejiro31 では QMK 標準のコンボ機能を使用しておらず、独自実装のコンボ機能を使用しています。

そのため、コンボの定義を行うにはソースコードを書き換える必要があります。

既存のコンボを変更したり、新しいコンボを追加したりするには 500 行目あたりの以下のコードを編集します。

```
<keymaps/jp_default/keymap.c>
// コンボ定義（順不同）
const combo_pair_t combo_pairs[] PROGMEM = {

    {KC_Q,    KC_Z,    KC_A,    _QWERTY},
    {KC_W,    KC_X,    KC_S,    _QWERTY},
    {KC_E,    KC_C,    KC_D,    _QWERTY},
    {KC_R,    KC_V,    KC_F,    _QWERTY},
    {KC_T,    KC_B,    KC_G,    _QWERTY},
    {KC_Y,    KC_N,    KC_H,    _QWERTY},
    {KC_U,    KC_M,    KC_J,    _QWERTY},
    {KC_I,    KC_COMM, KC_K,    _QWERTY},
    {KC_O,    KC_DOT,  KC_L,    _QWERTY},
    {KC_P,    KC_SLSH, KC_SCLN, _QWERTY},
    {KC_MINS, KC_BSLS, KC_QUOT, _QWERTY},
    {KC_LBRC, KC_RBRC, KC_EQL,  _QWERTY},
    {KC_V,    KC_B,    KC_TAB,  _QWERTY},
    {KC_R,    KC_T,    KC_ESC,  _QWERTY},
    {KC_N,    KC_M,    KC_BSPC, _QWERTY},
    {KC_Y,    KC_U,    KC_DEL,  _QWERTY},

    {KC_1,    KC_7,    KC_4,     _NUMBER},
    {KC_2,    KC_8,    KC_5,     _NUMBER},
    {KC_3,    KC_9,    KC_6,     _NUMBER},
    {KC_0,    KC_DZ,   KC_TZ,    _NUMBER},
    {KC_DOT,  KC_MINS, KC_COMMA, _NUMBER},
    {KC_9,    KC_DOT,  KC_TAB,   _NUMBER},
    {KC_3,    KC_MINS, KC_ESC,   _NUMBER},
    {KC_PGDN, KC_LEFT, KC_BSPC,  _NUMBER},
    {KC_PGUP, KC_HOME, KC_DEL,   _NUMBER},
};
```

例えば、 QWERTY レイヤーで V キーと M キーの同時押しで Enter キーを出力するコンボを追加したい場合は、以下のようなコードを追加します。

```
<keymaps/via/keymap.c>
    {KC_V,    KC_M,    KC_ENT,  _QWERTY},
```

ただし、三キー同時押し以上のコンボは現在サポートされていないためご注意ください。

また、コンボの出力キーコードをコンボの要素として使うこともできません。例えば、 QWERTY レイヤーで F キーと J キーの同時押しコンボは定義できません。

### config.h の設定

Mejiro31 のファームウェアは QMK ですので、標準で利用できる`config.h`という設定ファイルがあり、ここで様々な設定を行うことができます。

例えば、キーの長押し時間を変更したい場合は`keyboards/jeebis/mejiro31/config.h`を開き、以下のコードを編集します。

```
<config.h>
#define TAPPING_TERM 200
```

ここで設定されている数値はミリ秒単位で、キーが長押しとして認識されるまでの時間を表しています。

例えば、`TAPPING_TERM`を 300 に設定すると、 300 ms 以上押された Mod-Tap のキーは長押しとして認識されるようになります。

このような`config.h`の設定は、 QMK の公式ドキュメントをご覧ください。
- [QMK Config Options](https://docs.qmk.fm/config_options)

## お問い合わせ

お問い合わせは`jeebis.iox@gmail.com`か、特に不具合等は Mejiro31 の GitHub リポジトリの [Issues](https://github.com/JEEBIS27/Mejiro31/issues) へお願いします。

[スタートページに戻る](../README.md)

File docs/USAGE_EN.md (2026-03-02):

# How to Use Mejiro31 ([Back to Start Page](../README.md))

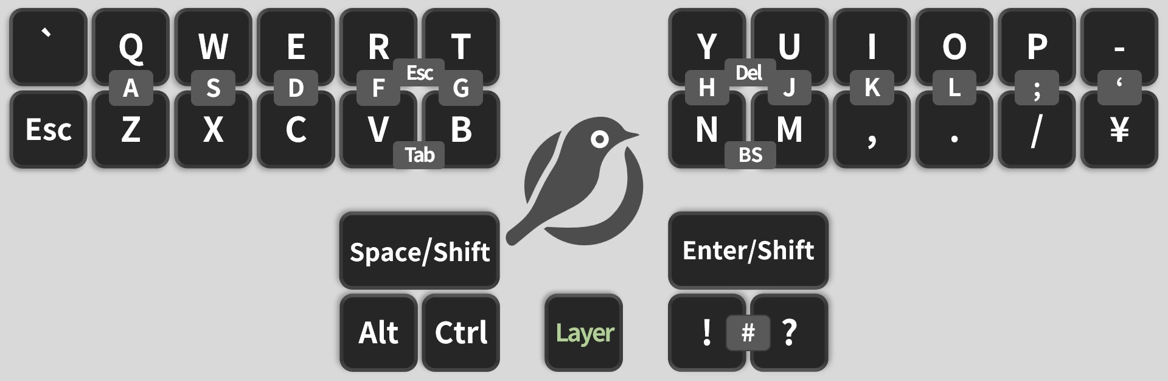
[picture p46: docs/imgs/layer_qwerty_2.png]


## Table of Contents
  1. [Key Layouts](#key-layouts)
     - [KEYBOARD Layer](#keyboard-layer)
     - [STENO Layer](#steno-layer)
     - [NUMBER Layer](#number-layer)
     - [FUNCTION Layer](#function-layer)
  2. [How to Remap Keys](#how-to-remap-keys)
  3. [Advanced Customization](#advanced-customization)
  4. [Contact Us](#contact-us)

## Key Layouts

The default key layout looks like this.

### KEYBOARD Layer

The KEYBOARD layer is the standard layer.

Every time you connect Mejiro31, it starts on this layer.

It uses [two-step compression](https://note.com/jeebis_keyboard/n/ncbc327906050), so about $1/3$ of the keys are typed by pressing adjacent keys simultaneously with the same finger.



If you want an alternate layout such as Dvorak or Colemak instead of QWERTY, see the firmware list in the [Start Page](../README.md) to download and flash your preferred layout. If you want another layout added, request it via GitHub [Issues](https://github.com/JEEBIS27/Mejiro31/issues).

The left and right spacebars are Space and Enter, respectively, but a long press turns them into Shift.

When Shift is held, the layout changes as shown below.



Tap the center layer key to switch to the STENO layer; hold it to switch to the NUMBER layer.

### STENO Layer

The STENO layer runs QMK Mejiro-style stenography by default.

Holding the QMK Mejiro-style toggle key (described later) switches this to the GEMINI layer.


The GEMINI layer is required for using stenography with Plover software.

It outputs codes dedicated to Plover.

You generally do not change this keymap.

If the keyboard suddenly stops typing, check that you have not switched to the GEMINI layer.

Tap the center layer key to go back to the KEYBOARD layer; hold it to switch to the NUMBER layer.

### NUMBER Layer

The NUMBER layer holds numbers, arrow keys, and other function keys.

The key above 0 is a 00 key that outputs two zeros.

When Shift is held, the layout changes as shown below.



On the far left, the top key is the QMK Mejiro-style toggle. Holding it disables Mejiro-style mode and activates the GEMINI layer.

On the far right, the top key (hold) toggles alternate layouts on or off, and the bottom key (hold) moves to the FUNCTION layer.

### FUNCTION Layer

The FUNCTION layer provides F1–F13 keys and media keys.

On the far left, the top key (hold) toggles a mode that allows US keyboard input even when the PC keyboard layout is set to JIS.

Mejiro31 outputs as a US keyboard, so if your PC is set to JIS layout, you should enable this mode for proper output.

By default, this mode is enabled.

Note that PC-side shortcuts remain JIS.

On the far right, the top key (hold) toggles a mode that changes the symbols on the QWERTY and NUMBER layers to standard keyboard layout.

When enabled, pressing `Shift + 2` on the NUMBER layer outputs `@`, for example.

## How to Remap Keys

First, download this file:
- [via_keymap.json](https://github.com/JEEBIS27/Mejiro31/releases/download/v0.0.0/via_keymap.json)

Next, open `VIA` in your browser and choose DESIGN.

(This link opens the DESIGN view directly.)

- [VIA/DESIGN](https://www.usevia.app/design)



In the DESIGN tab, click `Load`.



Select the JSON file you downloaded. If it loads correctly, the layout appears as shown below.



After loading the JSON, move to the CONFIGURE tab.



Click `Authorize device`, then choose Mejiro31 in the popup to connect.



You will enter the keymap editor. Click a key on the keyboard, then pick a new key from the list below to remap it.



Once you do this setup, future changes only require opening the VIA CONFIGURE tab and connecting Mejiro31; you do not need to load the JSON again.

(VIA cannot redefine simultaneous presses of vertical neighbors, so in practice you can only change keys on the NUMBER and FUNCTION layers. For alternate layouts like Dvorak or Colemak, see [Advanced Customization](#advanced-customization).)

## Advanced Customization

### Outline
  1. [How to perform advanced customization](#how-to-perform-advanced-customization)
     - [Fork the firmware repository](#fork-the-firmware-repository)
     - [Set up the firmware build environment](#set-up-the-firmware-build-environment)
  2. [Examples of advanced customization](#examples-of-advanced-customization)
     - [Language settings per layer](#language-settings-per-layer)
     - [Alternate layout settings](#alternate-layout-settings)
     - [Define alternate layouts](#define-alternate-layouts)
     - [Detailed combo settings](#detailed-combo-settings)
     - [config.h settings](#configh-settings)

Mejiro31 supports deeper customization by editing its QMK firmware settings to meet finer needs.

### How to perform advanced customization

To customize deeply, fork the Mejiro31 firmware repository into your account and set up a build environment.

Build the modified source and flash the resulting firmware onto Mejiro31 to apply your changes.

### Fork the firmware repository

Visit [github.com](https://github.com/).



If you do not have a GitHub account, sign up first.

Then open the Mejiro31 QMK firmware repository:
- [JEEBIS27/qmk_firmware](https://github.com/JEEBIS27/qmk_firmware)



Click the `Fork` button in the top right to fork it to your account.



After clicking `Fork`, you will see the creation screen. Click `Create fork` to finish.



Your account now has a fork of the Mejiro31 QMK firmware repository.

Open your fork and click the green `Code` button to copy the URL.



You will use this URL in [Set up the firmware build environment](#set-up-the-firmware-build-environment).

### Set up the firmware build environment

The steps differ by OS; these guides are helpful:

- [QMK setup for Windows (official docs)](https://docs.qmk.fm/#/newbs_getting_started?id=windows-setup)
- [QMK setup for macOS (official docs)](https://docs.qmk.fm/#/newbs_getting_started?id=macos-setup)

When you see a command like `git clone <repository_url>`, use the URL of your forked repository copied earlier.

### Examples of advanced customization

Editing the firmware source allows fine-grained customization.

#### Language settings per layer

Mejiro31 can automatically switch the IME according to the set language whenever a layer changes.

This feature lets the center layer key act both as a keyboard/steno mode toggle and an IME switcher.

By default, steno mode uses Mejiro-style for Japanese input and keyboard mode uses English input.

For advanced customization, for example, if you want to use romaji for Japanese and stenography for English, you can configure the QWERTY layer to turn IME ON and the GEMINI layer to turn IME OFF.

To configure Mejiro31's language settings, open `keyboards/jeebis/mejiro31/keymaps/en_qwerty/keymap.c` in your forked repository.

Around line 72 you will find:

```
<keymaps/en_qwerty/keymap.c>
// 0:unused, 1:English, 2:Japanese, 3:no change
static int stn_lang = 2; // Language for steno mode
static int kbd_lang = 1; // Language for keyboard mode
```

Here, `stn_lang` represents the language setting for the GEMINI layer (steno mode), and `kbd_lang` represents the language setting for the QWERTY layer (keyboard mode).

Set each variable to one of these values:

| Value | Language |
| ----- | --- |
| 1 | English  |
| 2 | Japanese |
| Other | No change |

To type Japanese in keyboard mode and English in steno mode, configure as follows:

```
<keymaps/en_qwerty/keymap.c>
static int stn_lang = 1; // Language for steno mode
static int kbd_lang = 2; // Language for keyboard mode
```

#### Alternate layout settings

Here is an example of using the Onishi layout for Japanese input and Graphite for English input.

First, open `keyboards/jeebis/mejiro31/keymaps/jp_default/keymap.c` in your forked repository.

Around line 73 you will find:

```
<keymaps/jp_default/keymap.c>
static alt_layout_def_t alt_en_layout = ALT_LAYOUT(qwerty);  // Layout for English mode
static alt_layout_def_t alt_jp_layout = ALT_LAYOUT(qwerty);  // Layout for Japanese mode
```

The `alt_en_layout` and `alt_jp_layout` variables default to `qwerty`.

You can change them to any supported alternate layout name to set different layouts for each language mode:

```
<keymaps/jp_default/keymap.c>
static alt_layout_def_t alt_en_layout = ALT_LAYOUT(graphite);  // Layout for English mode
static alt_layout_def_t alt_jp_layout = ALT_LAYOUT(o24);  // Layout for Japanese mode
```

Once you configure this, the Eisu/Kana key on the NUMBER layer (lower right thumb) will automatically switch both the IME and the alternate layout together.

#### Define alternate layouts

Next, we will show how to define your own custom alternate layout keymap.

First, open `keyboards/jeebis/mejiro31/alt_layouts_definitions.h` in your forked repository.

For example, around line 67 you will find:

```
<keyboards/jeebis/mejiro31/alt_layouts_definitions.h>
// ====== GRAPHITE ======
static const alt_mapping_t graphite[] PROGMEM = {

    {KC_Q,    KC_B,    KC_B},
    {KC_W,    KC_L,    KC_L},
    {KC_E,    KC_D,    KC_D},
    {KC_R,    KC_W,    KC_W},
    {KC_T,    KC_Z,    KC_Z},
    {KC_Y,    KC_QUOT, KC_UNDS},
    {KC_U,    KC_F,    KC_F},
    {KC_I,    KC_O,    KC_O},
    {KC_O,    KC_U,    KC_U},
    {KC_P,    KC_J,    KC_J},
    {KC_MINS, KC_SCLN, KC_COLN},

    {KC_A,    KC_N,    KC_N},
    {KC_S,    KC_R,    KC_R},
    {KC_D,    KC_T,    KC_T},
    {KC_F,    KC_S,    KC_S},
    {KC_G,    KC_G,    KC_G},
    {KC_H,    KC_Y,    KC_Y},
    {KC_J,    KC_H,    KC_H},
    {KC_K,    KC_A,    KC_A},
    {KC_L,    KC_E,    KC_E},
    {KC_SCLN, KC_I,    KC_I},
    {KC_QUOT, KC_COMM, KC_QUES},

    {KC_Z,    KC_Q,    KC_Q},
    {KC_X,    KC_X,    KC_X},
    {KC_C,    KC_M,    KC_M},
    {KC_V,    KC_C,    KC_C},
    {KC_B,    KC_V,    KC_V},
    {KC_N,    KC_K,    KC_K},
    {KC_M,    KC_P,    KC_P},
    {KC_COMM, KC_DOT,  KC_RABK},
    {KC_DOT,  KC_MINS, KC_DQUO},
    {KC_SLSH, KC_SLSH, KC_LABK},
    {KC_BSLS, KC_BSLS, KC_PIPE},

};
```

This defines the keymap for the Graphite layout.

You can copy this and modify it to create your own custom layout.

The definition format is: each line contains:
1. QWERTY keycode (left)
2. Alternate layout keycode (middle)
3. Alternate layout keycode when Shift is pressed (right)

#### Detailed combo settings

Mejiro31 uses a custom combo implementation instead of the standard QMK combo feature.

To define combos, you need to edit source code.

To change existing combos or add new ones, edit the code around line 373:

```
<keymaps/jp_qwerty/keymap.c>
// Combo definitions (order-independent)
const combo_pair_t combo_pairs[] PROGMEM = {

    {KC_Q,    KC_Z,    KC_A,    _QWERTY},
    {KC_W,    KC_X,    KC_S,    _QWERTY},
    {KC_E,    KC_C,    KC_D,    _QWERTY},
    {KC_R,    KC_V,    KC_F,    _QWERTY},
    {KC_T,    KC_B,    KC_G,    _QWERTY},
    {KC_Y,    KC_N,    KC_H,    _QWERTY},
    {KC_U,    KC_M,    KC_J,    _QWERTY},
    {KC_I,    KC_COMM, KC_K,    _QWERTY},
    {KC_O,    KC_DOT,  KC_L,    _QWERTY},
    {KC_P,    KC_SLSH, KC_SCLN, _QWERTY},
    {KC_MINS, KC_BSLS, KC_QUOT, _QWERTY},
    {KC_LBRC, KC_RBRC, KC_EQL,  _QWERTY},
    {KC_V,    KC_B,    KC_TAB,  _QWERTY},
    {KC_R,    KC_T,    KC_ESC,  _QWERTY},
    {KC_N,    KC_M,    KC_BSPC, _QWERTY},
    {KC_Y,    KC_U,    KC_DEL,  _QWERTY},

    {KC_1,    KC_7,    KC_4,     _NUMBER},
    {KC_2,    KC_8,    KC_5,     _NUMBER},
    {KC_3,    KC_9,    KC_6,     _NUMBER},
    {KC_0,    KC_DZ,   KC_TZ,    _NUMBER},
    {KC_DOT,  KC_MINS, KC_COMMA, _NUMBER},
    {KC_9,    KC_DOT,  KC_TAB,   _NUMBER},
    {KC_3,    KC_MINS, KC_ESC,   _NUMBER},
    {KC_PGDN, KC_LEFT, KC_BSPC,  _NUMBER},
    {KC_PGUP, KC_HOME, KC_DEL,   _NUMBER},
};
```

For example, to add a combo on the QWERTY layer that outputs Enter when pressing V and M together, add:

```
<keymaps/via/keymap.c>
    {KC_V,    KC_M,    KC_ENT,  _QWERTY},
```

Note: combos of three or more simultaneous keys are not supported.

Also, you cannot use the output keycode as part of the combo. For example, a combo on the QWERTY layer that outputs F when pressing F and J together cannot be defined.

#### config.h settings

Mejiro31 runs QMK firmware, so standard `config.h` settings are available for many options.

To change the hold time for keys, open `keyboards/jeebis/mejiro31/config.h` and edit:

```
<config.h>
#define TAPPING_TERM 200
```

This value is in milliseconds and defines how long a key must be held to count as a hold.

For example, setting `TAPPING_TERM` to 300 makes Mod-Tap keys register as holds after 300 ms.

See the QMK docs for other `config.h` options:
- [QMK Config Options](https://docs.qmk.fm/config_options)

## Contact Us

Email `jeebis.iox@gmail.com`, or for issues, open an [Issue on the Mejiro31 GitHub repo](https://github.com/JEEBIS27/Mejiro31/issues).

[Back to Start Page](../README.md)

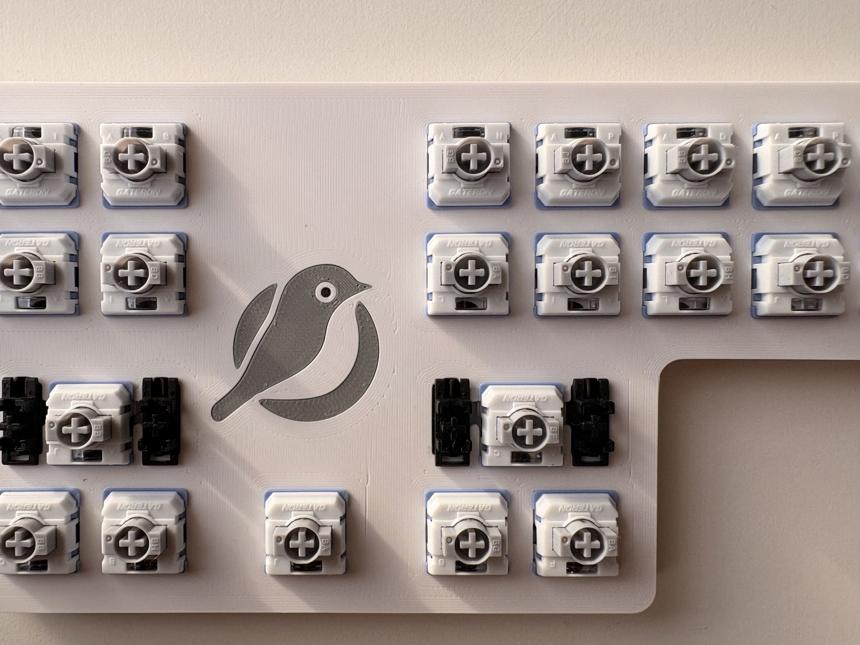
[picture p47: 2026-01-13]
docs/imgs/build_switches.jpeg

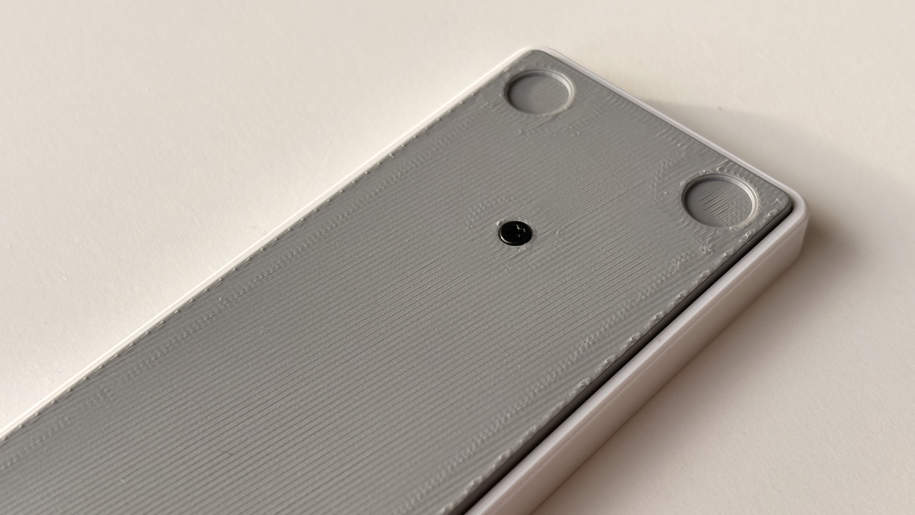
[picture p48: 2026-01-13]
docs/imgs/build_edge.jpeg

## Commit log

2025-12-18 最新のファイルに更新
    [Mejiro31-PCBA_bottom.3mf, Mejiro31-PCBA_bottom.stl, Mejiro31-PCBA_eye.3mf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]
2025-12-18 コンボのしきい値を少なく変更
2025-12-18 vid・pidの値をユニークな数字に変更
2025-12-18 OS検知の機能を追加
2025-12-18 モディファイアキーの配置を一部変更、OSごと(Mac・Windows)での操作感を統一
2025-12-18 最新の変更を反映
2025-12-18 コンボの閾値を増やした
2025-12-19 次の接続時にも設定を引き継ぐように変更
2025-12-19 コンボの命名規則を変更、is_jis_modeの値を次の接続時にも引き継ぐように変更
2025-12-20 keymapを変更
2025-12-20 Viaの設定ファイルを追加
2025-12-20 変更の適応
2025-12-20 最新の変更を適応
2025-12-21 a2jを廃止
2025-12-24 ファイルを追加
2025-12-24 写真を追加
2025-12-24 変更を適応
2026-01-02 ファイル名を変更
2026-01-02 不具合を修正
2026-01-02 ３Dデータとビルド済みファームウェアファイルを削除
    [Mejiro31-PCBA_bottom.3mf, Mejiro31-PCBA_bottom.stl, Mejiro31-PCBA_eye.3mf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]
2026-01-02 ドキュメントを追加
2026-01-02 初期設定を変更
2026-01-02 お問い合わせを追加
2026-01-02 qmk_firmwareリポジトリとかぶっていた内容を削除
2026-01-02 目次の変更、config.hの章の追加
2026-01-02 URL を修正
2026-01-02 取得ファイルと埋め込みリンクの文字を統一
2026-01-12 大文字に名前を変更
2026-01-12 最新のファームウェアの変更に対応
2026-01-13 最新の状態に変更
2026-01-13 Merlin配列を追加
2026-01-14 誤字等を修正
2026-01-21 英語の説明を追加、最新の配列に変更
2026-01-21 必要工具にペンチを追加
2026-01-21 最新のコードに説明を変更
2026-01-24 最新バージョンにファームウェアを変更
2026-01-24 レイヤーの写真を追加
2026-01-24 最新のバージョンにファームウェアを変更
2026-01-24 最新のバーションのファームウェアに説明を変更
2026-01-24 写真を変更
2026-02-18 最新のファームウェアにリンクを変更
2026-02-24 最新の変更を適用。
2026-03-01 最新のキーマップに差し替え
2026-03-03 リンクを修正
2026-03-03 タイポ修正
2026-03-09 zhのような記号定義の表を追加。
2026-03-10 ファームウェアの最新リリースのバージョンに変更。
2026-03-11 v0.3.6に対応
2026-03-11 GoogleIMEのローマテーブルのリンクをついか。
2026-03-16 v0.3.7に
2026-03-21 v0.3.8にアップデート
2026-10-25 Mejiro31の説明を現行ファームウェア仕様へ更新
2026-10-31 Default firmware write lock to off and show current lock state
